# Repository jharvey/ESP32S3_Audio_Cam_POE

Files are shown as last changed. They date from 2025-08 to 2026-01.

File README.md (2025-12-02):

# ESP32S3_Audio_Cam_POE

This is a PCB layout for ESP32S3 with OV2640 / OV5640 camera. This was designeed with KiCAD version 9. 
The boards major features include:
* Camera.
* 2 way audio.
* Hardwired Ethernet including POE.
* Camera pan / tilt servos and lamp control.
* record to SD card.
* misc outputs to drive misc motors or similar outputs. 
* Battery powered option with Lion type of battery. 
* Stream video to NVR recording station. 

## Firmware
Firmware found here https://github.com/jharvey/ESP32-CAM_MJPEG2SD

Changes up to version 0.1:
* Initial layout

## Purpose

The layout design intent is to make a hardwired intercom system which includes options for camera, making a near equivilant of a doorbell camera. Hardwired means it's not susceptibale to RF jaming, or similar attacks. It can be battery powered at the ethernet switch source so it can handle power outagaged. Lighting controls allow night time spot light, and day time spot light controls. Pan, Tilt, Rotate could potentailly allow a laser pointer to distract bad players if things go bump in the night. 

## Installation
After cloning, don't forget to check out the submodule. 

TBD currently has not had it's first spin. TBD

## 3D case
See 3D case found here
TBD create file in OnShape and post link here. TBD

## 3D pictures from KICAD
<div align="center">
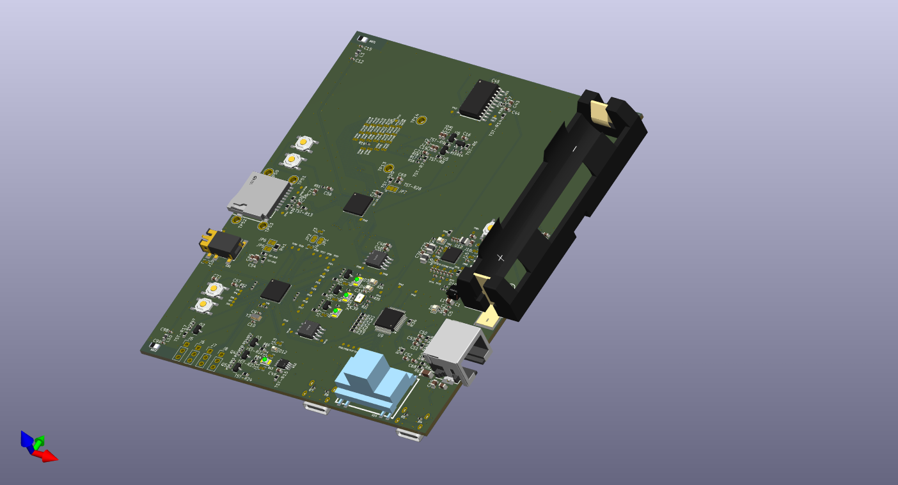
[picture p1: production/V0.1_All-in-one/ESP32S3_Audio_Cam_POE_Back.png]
ESP32S3_Cam_POE_Back

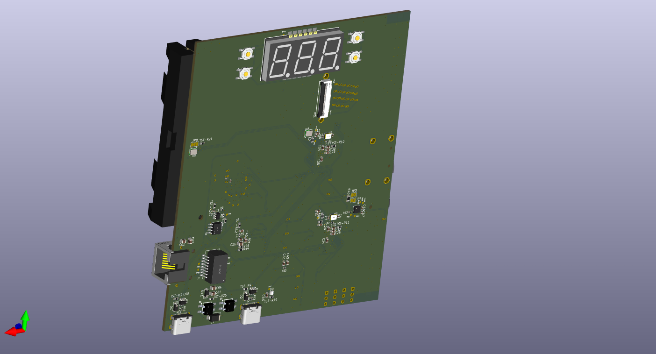
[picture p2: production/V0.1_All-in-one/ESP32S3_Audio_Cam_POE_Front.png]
ESP32S3_Cam_POE_Front

<div align="left">

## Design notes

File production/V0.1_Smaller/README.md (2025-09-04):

# ESP32S3_Audio_Cam_POE

This is a PCB layout for ESP32S3 with OV2640 / OV5640 camera. This was designeed with KiCAD version 9. 
The boards major features include:
* Camera.
* 2 way audio.
* Hardwired Ethernet including POE.
* Camera pan / tilt servos and lamp control.
* record to SD card.
* Stream video to NVR recording station. 

Changes up to version 0.1:
* Initial layout

## Installation
After cloning, don't forget to check out the submodule. 

TBD currently has not had it's first spin. TBD

## 3D case
See 3D case found here
TBD create file in OnShape and post link here. TBD

## 3D pictures from KICAD
<div align="center">
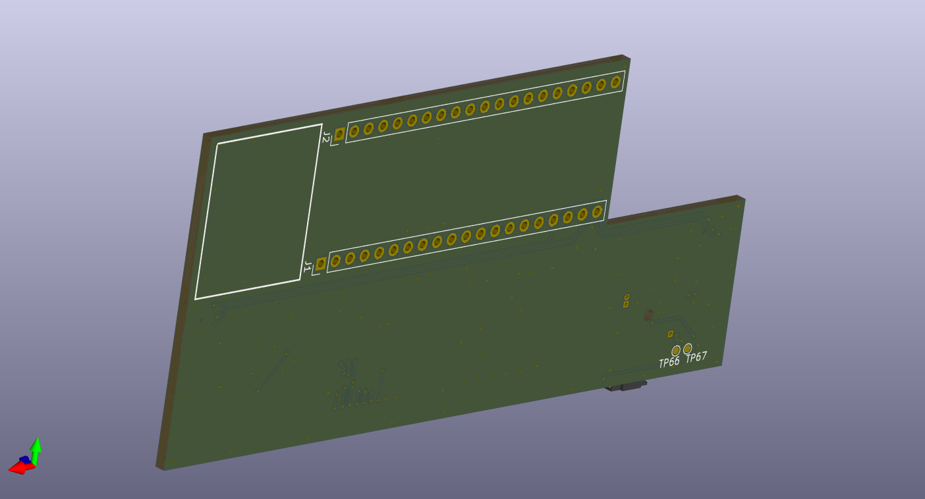
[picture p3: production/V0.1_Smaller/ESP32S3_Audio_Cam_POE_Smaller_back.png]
ESP32S3_Cam_POE_Back

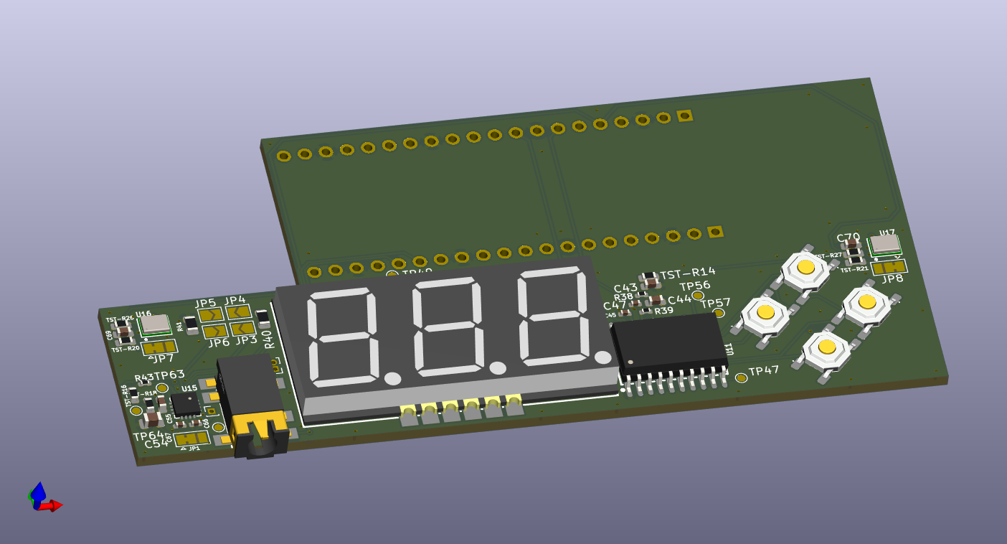
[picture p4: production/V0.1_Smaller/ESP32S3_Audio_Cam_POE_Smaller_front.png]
ESP32S3_Cam_POE_Front

<div align="left">

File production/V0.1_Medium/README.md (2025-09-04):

# ESP32S3_Audio_Cam_POE

This is a PCB layout for ESP32S3 with OV2640 / OV5640 camera. This was designeed with KiCAD version 9. 
The boards major features include:
* Camera.
* 2 way audio.
* Hardwired Ethernet including POE.
* Camera pan / tilt servos and lamp control.
* record to SD card.
* misc outputs to drive misc motors or similar outputs. 
* Battery powered option with Lion type of battery. 
* Stream video to NVR recording station. 

## Firmware
Firmware found here https://github.com/jharvey/ESP32-CAM_MJPEG2SD

Changes up to version 0.1:
* Initial layout

## Purpose

The layout design intent is to make a hardwired intercom system which includes options for camera, making a near equivilant of a doorbell camera. Hardwired means it's not susceptibale to RF jaming, or similar attacks. It can be battery powered at the ethernet switch source so it can handle power outagaged. Lighting controls allow night time spot light, and day time spot light controls. Pan, Tilt, Rotate could potentailly allow a laser pointer to distract bad players if things go bump in the night. 

## Installation
After cloning, don't forget to check out the submodule. 

TBD currently has not had it's first spin. TBD

## 3D case
See 3D case found here
TBD create file in OnShape and post link here. TBD

## 3D pictures from KICAD
<div align="center">
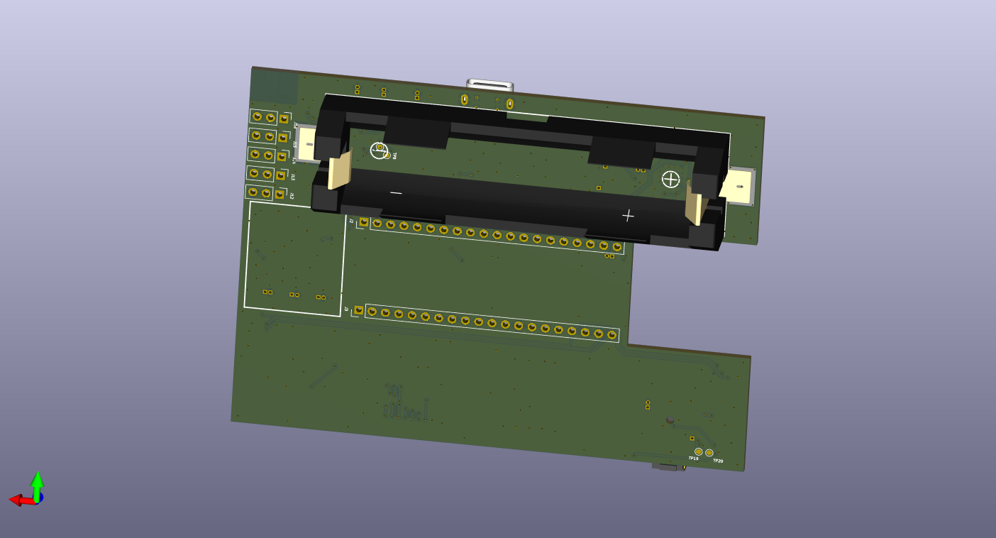
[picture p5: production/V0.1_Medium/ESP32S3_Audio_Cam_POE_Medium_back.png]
ESP32S3_Cam_POE_Back

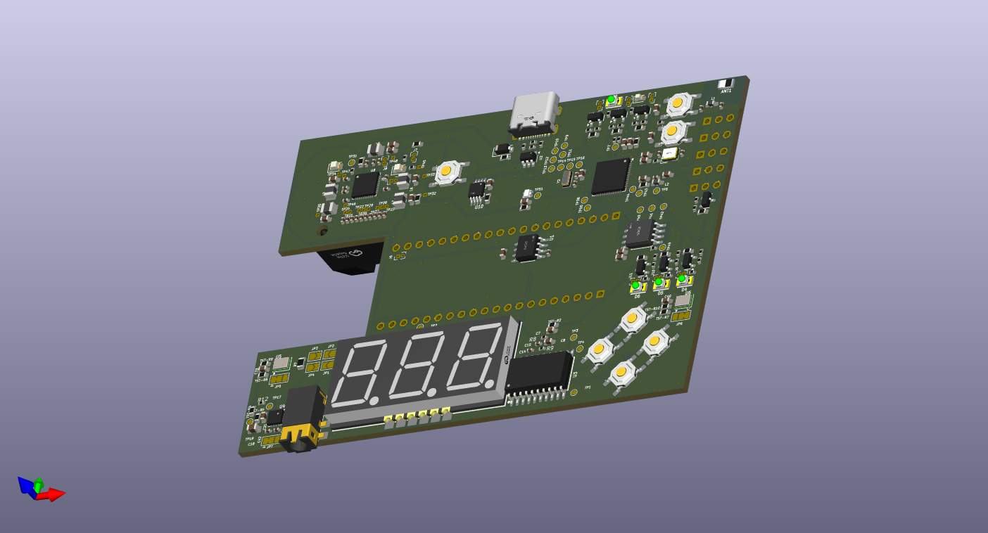
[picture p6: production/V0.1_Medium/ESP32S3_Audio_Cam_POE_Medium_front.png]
ESP32S3_Cam_POE_Front

<div align="left">

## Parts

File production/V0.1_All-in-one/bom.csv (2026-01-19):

Designator | Footprint | Quantity | Value | LCSC Part #
ANT1, ANT2 | ANT-SMD_L3.2-W1.6-KH-3216F245C04 | 2 | KH-3216-H0209 | C2925417
ANT3 | ANT-SMD_H2U646MHLQ0200 | 1 | H2U646MHLQ0200 | C5370061
BOOT1, BOOT2, PB1, PB2, PB3, PB4, PB5, RST2, RST3 | SW-SMD_4P-L5.1-W5.1-P3.70-LS6.5-TL-2 | 9 | Tactile Button, 160gf | C318884
BT1 | BATTERY-SMD_18650-1S-L77.1-W20.7-1 | 1 | BH-18650-B1BA002 | C2988620
C1 | C_0805 | 1 | 4.7uF | C1779
C10, C9 | C_0402 | 2 | 20pF | C1554
C100, C101, C11, C13, C19, C20, C21, C24, C25, C27, C28, C29, C30, C31, C32, C35, C37, C38, C41, C44, C46, C49, C5, C55, C56, C57, C58, C68, C69, C70, C71, C72 | C_0603 | 32 | 100nF | C14663
C102, C14, C74, C8 | C_0402 | 4 | 10uF | C15525
C103 | C_0805 | 1 | 10u | C15850
C104 | C_0402 | 1 | 4.7pF | C1569
C105, C12, C98 | C_0402 | 3 | 3.3pF | C1565
C106, C3, C33, C34, C4, C6, C7 | C_0402 | 7 | 10pF | C32949
C15, C99 | C_0402 | 2 | 1pF | C1550
C16, C17, C18, C23, C26, C42, C43, C48 | C_0603 | 8 | 1uF | C15849
C2 | C_0402 | 1 | 1nF | C1523
C22 | C_0402 | 1 | 15pF | C1548
C36, C54 | C_0805 | 2 | 10uF | C440198
C39 | C_0402 | 1 | 10nF | C15195
C40 | C_0603 | 1 | 4.7uF | C19666
C45, C47 | C_0402 | 2 | 100pF | C1546
C50, C51 | C_0603 | 2 | 6.8nF | C1631
C52, C53 | C_0603 | 2 | 220nF | C21120
C59, C60, C62, C63 | C_0805 | 4 | 100nF | C28233
C61 | C_0805 | 1 | 10uF | C15850
C64 | C_0805 | 1 | 22uF | C45783
C65 | C_1206 | 1 | 1nF | C9196
C66, C67 | C_0402 | 2 | 220pF | C1530
C73, C88, C90, C91, C92, C93, C94 | C_0402 | 7 | 1uF | C52923
C75, C76, C77, C78, C95, C97 | C_0603 | 6 | 22uF | C59461
C79, C80, C81, C82, C83, C84, C85, C86, C87, C96 | C_0402 | 10 | 2.2uF | C12530
C89 | C_0402 | 1 | 4.7uF | C23733
CARD1 | TF-PUSH-SD-CARD_C393941 | 1 | TF PUSH | C393941
CN1 | SMD_3.5mm_Audio_Connectors_(Headphones)_C707223 | 1 | PJ-316C-6A | C707223
D1, D11, D2 | D_SOD-123 | 3 | 1N4148W | C81598
D10 | D_0603 | 1 | Red | C2286
D12 | D_0603 | 1 | White | C2290
D13, D16, D17, D18 | IR-LED_C131280 | 4 | IR | C131280
D14, D3 | D_0805 | 2 | Yellow | C2296
D15, D4, D8 | D_0805 | 3 | Green | C2297
D5, D6 | MB6S-C82584 | 2 | MB6S | C82584
D7 | D_SMA | 1 | SMAJ58A | C19077554
D9 | LED-SMD_4P-L1.6-W1.5_XL-1615RGBC-WS2812B | 1 | WS2812B | C5349954
DISP1 | 3x7-seg_LED-RED_C2913084 | 1 | SLS0563DRA1GD | C2913084
FPC1 | OV2640_connector_AFC01-S24FCC-00 | 1 | AFC01-S24FCC-00 | C262276
J1, J2 | TYPE-C-SMD_HX-TYPE-C-16PIN | 2 | Connector, USB-TYPE-C-16P | C2927039
J10, J11, J12, J13, J14, J15, J16, J17, J18, J19, J3, J4 | PinHeader_1x02_P1.00mm_Vertical | 12 | Conn_01x02
J5, J6, J7, J8 | PinHeader_1x03_P2.54mm_Vertical | 4 | Conn_01x03
J9 | HC-RJ45-055-4_C3000211 | 1 | HC-RJ45-055-4_8P8C_Shielded | C3000211
JP1, JP2 | SolderJumper-2_P1.3mm_Bridged_RoundedPad1.0x1.5mm | 2 | Jumper_2_Small_Bridged
L1 | L_Wurth_WE-LQSH-4020 | 1 | 2.2uH | C135262
L10, L3, L4 | L_0402 | 3 | 3.9nH,300mA | C14033
L11, L2 | 0603 | 2 | 2nH | C29682
L5, L6, L7, L8, L9 | 1008 | 5 | 1uH,3.3A | C435392
NTC1 | R_0402 | 1 | NTC | C3018545
Q1, Q2, Q3, Q4, Q5, Q6, Q7, Q8 | Q_SOT-23 | 8 | AO3401A | C15127
R1, R2, R3 | R_0402 | 3 | 22Ω | C25092
R10, R11, R12, R13 | R_0402 | 4 | 33Ω | C25105
R14, R42, R54, R55, R56, R79, R8, R82 | R_0402 | 8 | 10MΩ | C26082
R15, R20, R43, R47, R57, R58, R63, R77, R80, R83 | R_0402 | 10 | 1MΩ | C26083
R16, R17, R18, R19, R28, R30, R31, R38, R39, R50, R51, R52, R53, R64, R65, R66, R67, R69, R70, R73, R75, R78, R81, R84 | R_0402 | 24 | 10kΩ | C25744
R21, R85, R86, R87 | R_0402 | 4 | 0Ω | C17168
R22, R23, R24, R25, R26, R27 | R_0603 | 6 | 20Ω | C22950
R29, R32, R36 | R_0603 | 3 | 12kΩ | C22790
R33, R37, R68, R71, R72, R9 | R_0402 | 6 | 100kΩ | C25741
R34, R35 | R_0402 | 2 | 680Ω | C25130
R4, R5, R6, R7 | R_0402 | 4 | 5.1kΩ | C25905
R40, R41 | R_0805 | 2 | 100kΩ | C149504
R44, R45, R46 | R_0603 | 3 | 47Ω | C23182
R48, R49 | R_0603 | 2 | 82Ω | C23255
R59, R60, R61, R62 | R_0603 | 4 | 75Ω | C4275
R74, R76 | R_0402 | 2 | 220kΩ | C25767
T1 | H1102NLT_C18584 | 1 | H1102NLT | C18584
TP1, TP10, TP11, TP12, TP131, TP15, TP16, TP17, TP18, TP19, TP2, TP20, TP21, TP22, TP23, TP24, TP25, TP26, TP27, TP28, TP29, TP3, TP30, TP31, TP32, TP33, TP34, TP35, TP36, TP37, TP38, TP39, TP4, TP40, TP41, TP42, TP43, TP44, TP45, TP46, TP47, TP48, TP49, TP5, TP54, TP55, TP56, TP57, TP58, TP59, TP6, TP60, TP61, TP62, TP63, TP64, TP65, TP66, TP67, TP68, TP7, TP8, TP85, TP9 | TestPoint_Pad_D1.0mm_SmallFootprint | 64 | TestPoint
TP100, TP101, TP102, TP103, TP104, TP105, TP106, TP107, TP108, TP109, TP110, TP111, TP112, TP113, TP114, TP115, TP116, TP117, TP118, TP119, TP120, TP121, TP122, TP123, TP124, TP125, TP126, TP127, TP128, TP129, TP69, TP70, TP71, TP72, TP73, TP74, TP75, TP76, TP77, TP78, TP79, TP80, TP81, TP82, TP83, TP84, TP86, TP87, TP88, TP89, TP90, TP91, TP92, TP93, TP94, TP95, TP96, TP97, TP98, TP99 | PinHeader_1x01_P1.00mm_Vertical_small-courtyard | 60 | TestPoint
TP13, TP14, TP50, TP51, TP52, TP53 | TestPoint_Plated_Hole_D2.0mm | 6 | TestPoint
TST-R1, TST-R10, TST-R11, TST-R12, TST-R13, TST-R14, TST-R15, TST-R16, TST-R17, TST-R18, TST-R19, TST-R2, TST-R20, TST-R21, TST-R22, TST-R23, TST-R24, TST-R25, TST-R26, TST-R27, TST-R28, TST-R29, TST-R3, TST-R30, TST-R31, TST-R32, TST-R33, TST-R4, TST-R5, TST-R6, TST-R7, TST-R8, TST-R9 | R_0603 | 33 | 0Ω | C21189
U1 | SOT-23-5 | 1 | TLV62568DBVR | C163219
U10, U13 | SOIC-8_L5.3-W5.3-P1.27-LS8.0-BL | 2 | W25Q128JVSIQ | C97521
U11 | digital tube drivers_c2962580 | 1 | TM1637 | C2962580
U12 | DS18B20_C695836 | 1 | DS18B20U(UMW) | C695836
U14 | DP9900M_C5380106 | 1 | DP9900M-5V | C5380106
U15 | MAX98357AETE+T_C910544 | 1 | MAX98357AETE+T
U16, U17 | ICS-43434_C5656610 | 2 | ICS-43434 | C5656610
U18 | QFN-40-1EP_5x5mm_P0.4mm_EP3.6x3.6mm_ThermalVias | 1 | AXP2101 | C3036461
U19 | RFM69HCW | 1 | RFM69HCW | C2844473
U2 | Current-sensor_MT9221CT-06BR5_C879632 | 1 | MT9221CT-06BR5 | C879632
U3, U4 | SOT-23-6 | 2 | USBLC6-2SC6 | C2827654
U5 | SOT-23-3 | 1 | XC6206-1.5NR | C2984869
U6 | SOT-23-3 | 1 | XC6206-2.8V | C41424780
U7, U8 | QFN-56-1EP_7x7mm_P0.4mm_EP4x4mm_ThermalVias | 2 | ESP32-S3 | C2913194
U9 | LQFP-48_7x7mm_P0.5mm | 1 | W5500 | C32843
X1 | OSC-SMD_4P-L3.2-W2.5-BL | 1 | X322525MOB4SI | C9006
Y1, Y2 | OSC-SMD_4P-L3.2-W2.5-BL_SIT8008BI | 2 | 40MHz, 15pF | C9010
Y3 | Crystal_SMD_3215-2Pin_3.2x1.5mm | 1 | 32.768KHz | C97604

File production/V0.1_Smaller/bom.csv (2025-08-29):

Designator | Footprint | Quantity | Value | LCSC Part #
C43 | C_0603 | 1 | 1uF | C15849
C44, C55, C69, C70 | C_0603 | 4 | 100nF | C14663
C45, C47 | C_0402 | 2 | 100pF | C1546
C54 | C_0805 | 1 | 10uF | C440198
C66, C67 | C_0402 | 2 | 220pF | C1530
CN1 | SMD_3.5mm_Audio_Connectors_(Headphones)_C707223 | 1 | PJ-316C-6A | C707223
DISP1 | 3x7-seg_LED-RED_C2913084 | 1 | SLS0563DRA1GD | C2913084
J1, J2 | PinHeader_1x20_P2.54mm_Vertical | 2 | Conn_01x20_Pin
J10 | PinHeader_1x02_P1.00mm_Vertical | 1 | Conn_01x02
PB1, PB2, PB4, PB5 | SW-SMD_4P-L5.1-W5.1-P3.70-LS6.5-TL-2 | 4 | Tactile Button, 160gf | C318884
R38, R39 | R_0402 | 2 | 10kΩ | C25744
R40, R41 | R_0805 | 2 | 100kΩ | C149504
R43 | R_0402 | 1 | 1MΩ | C26083
TP1 | PinHeader_1x01_P1.00mm_Vertical | 1 | TestPoint
TP47, TP49, TP56, TP57, TP63, TP64, TP66, TP67, TP85 | TestPoint_Pad_D1.0mm | 9 | TestPoint
TST-R14, TST-R16, TST-R18, TST-R20, TST-R21, TST-R26, TST-R27 | R_0603 | 7 | 0Ω | C21189
U11 | digital tube drivers_c2962580 | 1 | TM1637 | C2962580
U15 | MAX98357AETE+T_C910544 | 1 | MAX98357AETE+T
U16, U17 | ICS-43434_C5656610 | 2 | ICS-43434 | C5656610

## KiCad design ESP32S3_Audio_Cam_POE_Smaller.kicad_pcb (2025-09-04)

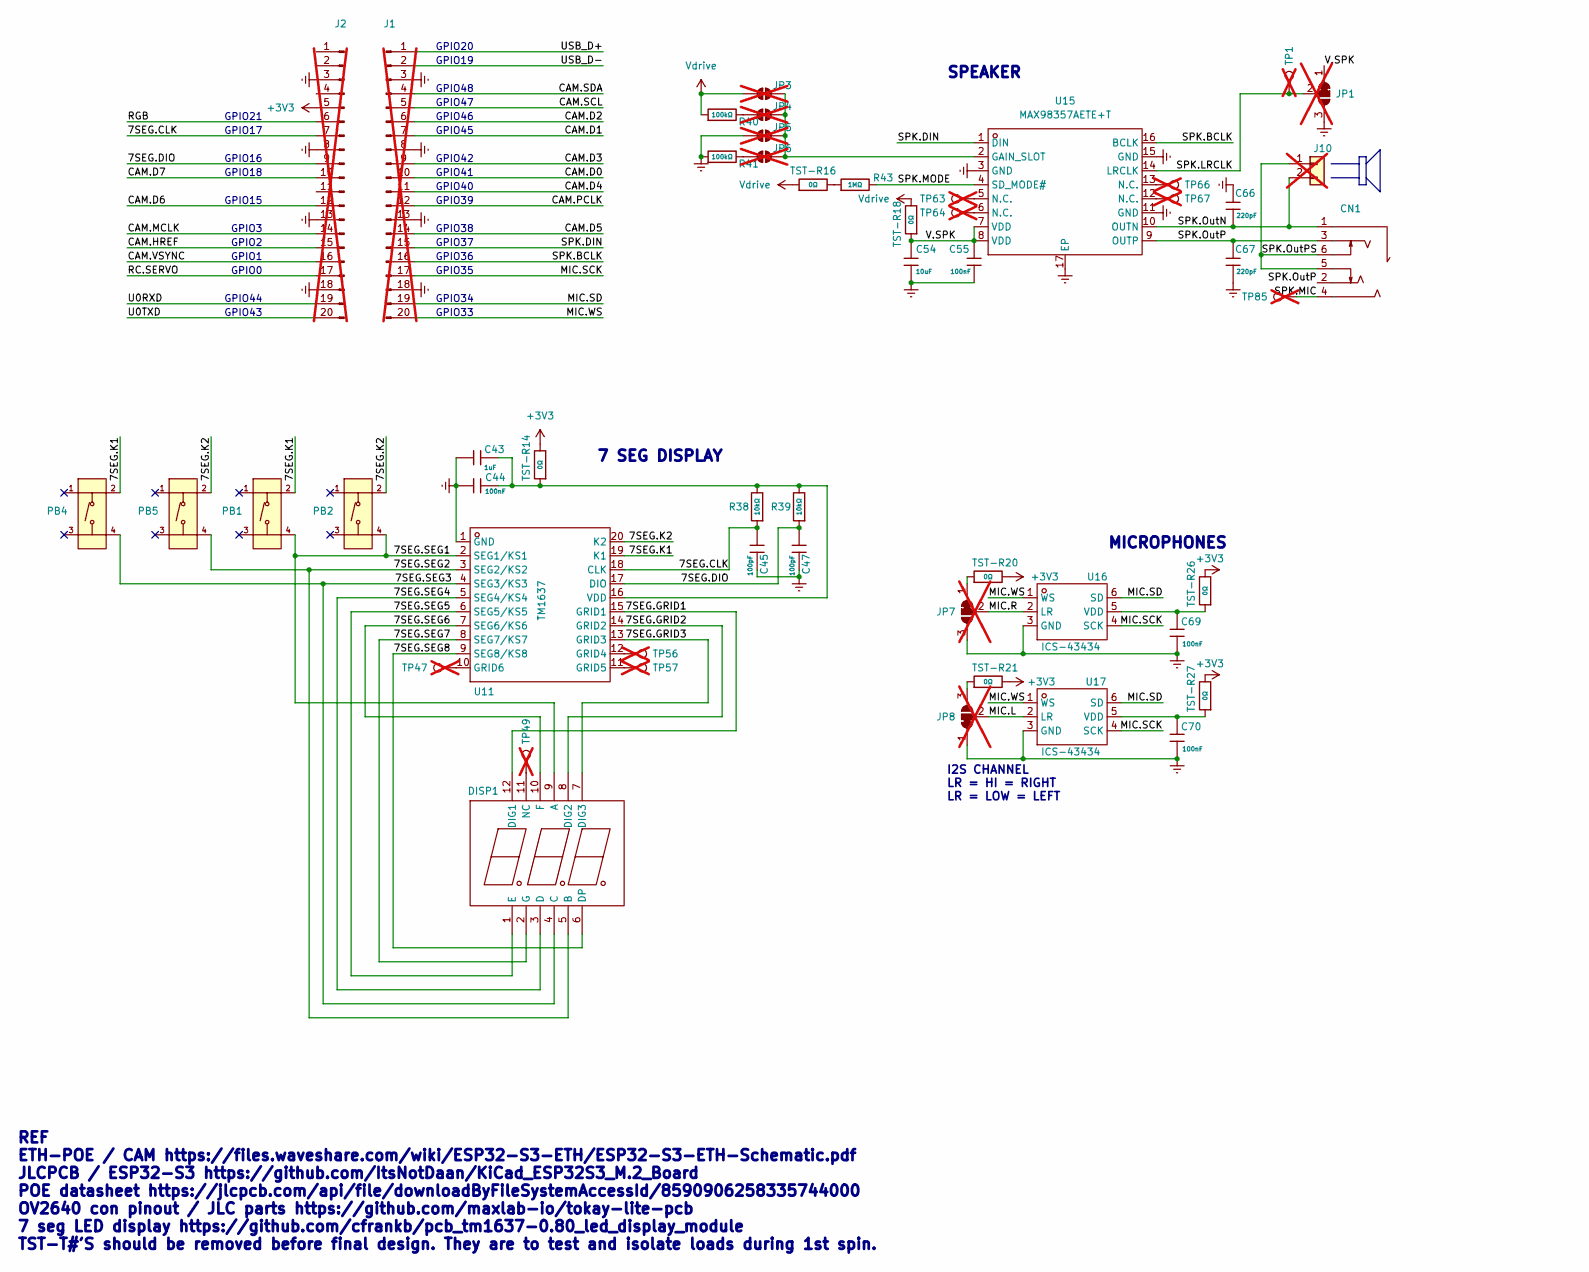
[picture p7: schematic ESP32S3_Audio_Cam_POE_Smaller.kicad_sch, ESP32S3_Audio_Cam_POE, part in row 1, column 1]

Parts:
C43: 1uF; C_0603; Voltage Rated 50V; Tolerance ±10%; Part CL10A105KB8NNNC; LCSC C15849
C44, C55, C69, C70: 100nF; C_0603; Voltage Rated 50V; Tolerance ±10%; Part CC0603KRX7R9BB104; LCSC C14663
C45, C47: 100pF; C_0402; Voltage Rated 50V; Tolerance ±5%; Part 0402CG101J500NT; LCSC C1546
C54: 10uF; C_0805; Voltage Rated 50V; Tolerance ±10%; Part GRM21BR61H106KE43L; LCSC C440198
C66, C67: 220pF; C_0402; Voltage Rated 50V; Tolerance ±10%; Part 0402B221K500NT; LCSC C1530
CN1: PJ-316C-6A; SMD_3.5mm_Audio_Connectors_(Headphones)_C707223; Manufacturer Part PJ-316C-6A; LCSC C707223
DISP1: SLS0563DRA1GD; 3x7-seg_LED-RED_C2913084; LCSC C2913084
J1, J2: Conn_01x20_Pin; PinHeader_1x20_P2.54mm_Vertical; not fitted
J10: Conn_01x02; PinHeader_1x02_P1.00mm_Vertical; not fitted
JP1, JP7, JP8: SolderJumper_3_Bridged12; SolderJumper-3_P1.3mm_Bridged12_Pad1.0x1.5mm; not fitted
JP3, JP4, JP5, JP6: SolderJumper_2_Open; SolderJumper-2_P1.3mm_Open_TrianglePad1.0x1.5mm; not fitted
PB1, PB2, PB4, PB5: Tactile Button, 160gf; SW-SMD_4P-L5.1-W5.1-P3.70-LS6.5-TL-2; Voltage Rating (Dc) 12V; Part TS-1187A-B-A-B; LCSC C318884
R38, R39: 10kΩ; R_0402; Overload Voltage (Max) 50V; Tolerance ±1%; Part 0402WGF1002TCE; LCSC C25744
R40, R41: 100kΩ; R_0805; Overload Voltage (Max) 150V; Tolerance ±1%; Part 0805W8F1003T5E; LCSC C149504
R43: 1MΩ; R_0402; Overload Voltage (Max) 50V; Tolerance ±1%; Part 0402WGF1004TCE; LCSC C26083
TP1: TestPoint; PinHeader_1x01_P1.00mm_Vertical; not fitted
TP47, TP49, TP56, TP57, TP63, TP64, TP66, TP67, TP85: TestPoint; TestPoint_Pad_D1.0mm; not fitted
TST-R14, TST-R16, TST-R18, TST-R20, TST-R21, TST-R26, TST-R27: 0Ω; R_0603; Overload Voltage (Max) 75V; Tolerance ±1%; Part 0603WAF0000T5E; LCSC C21189
U11: TM1637; digital tube drivers_c2962580; LCSC C2962580
U15: MAX98357AETE+T; MAX98357AETE+T_C910544; Manufacturer Part MAX98357AETE+T
U16, U17: ICS-43434; ICS-43434_C5656610; LCSC C5656610

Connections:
+3V3: J2.5, TST-R14.2, TST-R20.2, TST-R21.2, TST-R26.2, TST-R27.2
/7SEG.CLK: C45.2, J2.7, R38.1, U11.18 (CLK)
/7SEG.DIO: C47.2, J2.9, R39.1, U11.17 (DIO)
/7SEG.GRID1: DISP1.12 (DIG1), U11.15 (GRID1)
/7SEG.GRID2: DISP1.8 (DIG2), U11.14 (GRID2)
/7SEG.GRID3: DISP1.7 (DIG3), U11.13 (GRID3)
/7SEG.K1: PB1.2 (B), PB4.2 (B), U11.19 (K1)
/7SEG.K2: PB2.2 (B), PB5.2 (B), U11.20 (K2)
/7SEG.SEG1: DISP1.9 (A), PB1.4 (D), PB2.4 (D), U11.2 (SEG1/KS1)
/7SEG.SEG2: DISP1.5 (B), PB5.4 (D), U11.3 (SEG2/KS2)
/7SEG.SEG3: DISP1.4 (C), PB4.4 (D), U11.4 (SEG3/KS3)
/7SEG.SEG4: DISP1.3 (D), U11.5 (SEG4/KS4)
/7SEG.SEG5: DISP1.1 (E), U11.6 (SEG5/KS5)
/7SEG.SEG6: DISP1.10 (F), U11.7 (SEG6/KS6)
/7SEG.SEG7: DISP1.2 (G), U11.8 (SEG7/KS7)
/7SEG.SEG8: DISP1.6 (DP), U11.9 (SEG8/KS8)
/CAM.D0: J1.10
/CAM.D1: J1.7
/CAM.D2: J1.6
/CAM.D3: J1.9
/CAM.D4: J1.11
/CAM.D5: J1.14
/CAM.D6: J2.12
/CAM.D7: J2.10
/CAM.HREF: J2.15
/CAM.MCLK: J2.14
/CAM.PCLK: J1.12
/CAM.SCL: J1.5
/CAM.SDA: J1.4
/CAM.VSYNC: J2.16
/MIC.L: JP8.2 (C), U17.2 (LR)
/MIC.R: JP7.2 (C), U16.2 (LR)
/MIC.SCK: J1.17, U16.4 (SCK), U17.4 (SCK)
/MIC.SD: J1.19, U16.6 (SD), U17.6 (SD)
/MIC.WS: J1.20, U16.1 (WS), U17.1 (WS)
/RC.SERVO: J2.17
/RGB: J2.6
/SPK.BCLK: J1.16, U15.16 (BCLK)
/SPK.DIN: J1.15, U15.1 (DIN)
/SPK.LRCLK: JP1.2 (C), TP1.1, U15.14 (LRCLK)
/SPK.MIC: CN1.4, TP85.1
/SPK.MODE: R43.2, U15.4 (SD_MODE#)
/SPK.OutN: C66.2, CN1.1, J10.2, U15.10 (OUTN)
/SPK.OutP: C67.1, CN1.2, CN1.3, U15.9 (OUTP)
/SPK.OutPS: CN1.5, CN1.6, J10.1
/U0RXD: J2.19
/U0TXD: J2.20
/USB_D+: J1.1
/USB_D-: J1.2
/V.SPK: C54.1, C55.1, JP1.1 (A), TST-R18.1, U15.7 (VDD), U15.8 (VDD)
COM: C43.1, C44.2, C45.1, C47.1, C54.2, C55.2, C66.1, C67.2, C69.1, C70.1, J1.3, J1.8, J1.13, J1.18, J2.3, J2.8, J2.13, J2.18, JP1.3 (B), JP5.1 (A), JP7.3 (B), JP8.1 (A), R41.1, U11.1 (GND), U15.3 (GND), U15.11 (GND), U15.15 (GND), U15.17 (EP), U16.3 (GND), U17.3 (GND)
unnamed: DISP1.11 (NC), TP49.1
unnamed: JP3.2 (B), JP4.2 (B), JP5.2 (B), JP6.2 (B), U15.2 (GAIN_SLOT)
unnamed: JP4.1 (A), R40.2
unnamed: JP6.1 (A), R41.2
unnamed: JP7.1 (A), TST-R20.1
unnamed: JP8.3 (B), TST-R21.1
unnamed: R43.1, TST-R16.2
unnamed: TP63.1, U15.5 (N.C.)
unnamed: TP64.1, U15.6 (N.C.)
unnamed: TP66.1, U15.13 (N.C.)
unnamed: TP67.1, U15.12 (N.C.)
unnamed: TP56.1, U11.12 (GRID4)
unnamed: TP57.1, U11.11 (GRID5)
unnamed: TP47.1, U11.10 (GRID6)
unnamed: C43.2, C44.1, R38.2, R39.2, TST-R14.1, U11.16 (VDD)
unnamed: C69.2, TST-R26.1, U16.5 (VDD)
unnamed: C70.2, TST-R27.1, U17.5 (VDD)
Vdrive: JP3.1 (A), R40.1, TST-R16.1, TST-R18.2

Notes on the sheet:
GPIO15
GPIO37
GPIO0
expected risky area -- camera connector pinout, is pin1 really pin 1 not 24? -- I2S microphones and amplifier, should they be the same lines like code suggests -- I2C, does this need pull up, or can internal pullup suffice? -- POE ethernet, complete unknown. Fingers crossed. TODO -- make office con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
GPIO21
MICROPHONES
GPIO46
GPIO36
GPIO34
I2S CHANNEL LR = HI = RIGHT LR = LOW = LEFT
GPIO1
GPIO20
GPIO3
GPIO18
GPIO48
GPIO41
GPIO33
GPIO19
GPIO44
REF ETH-POE / CAM https://files.waveshare.com/wiki/ESP32-S3-ETH/ESP32-S3-ETH-Schematic.pdf JLCPCB / ESP32-S3 https://github.com/ItsNotDaan/KiCad_ESP32S3_M.2_Board POE datasheet https://jlcpcb.com/api/file/downloadByFileSystemAccessId/8590906258335744000 OV2640 con pinout / JLC parts https://github.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
SPEAKER
GPIO47
GPIO35
GPIO43
GPIO42
GPIO40
7 SEG DISPLAY
GPIO2
GPIO45
GPIO38
GPIO39
GPIO17
GPIO16

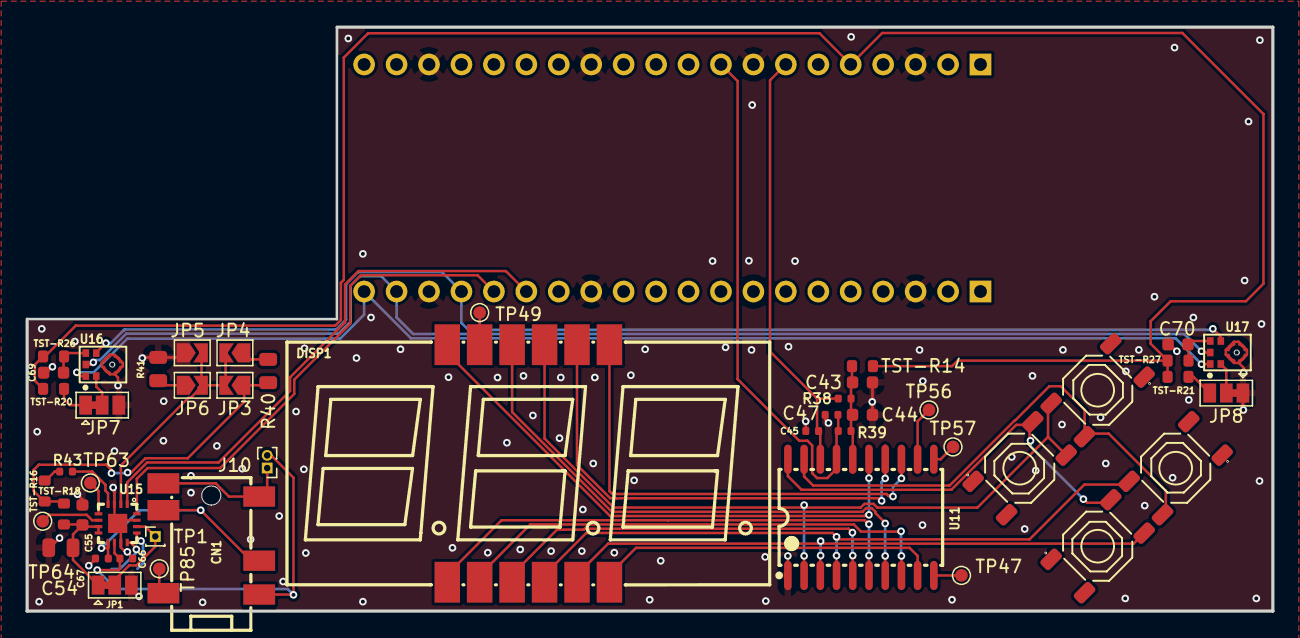
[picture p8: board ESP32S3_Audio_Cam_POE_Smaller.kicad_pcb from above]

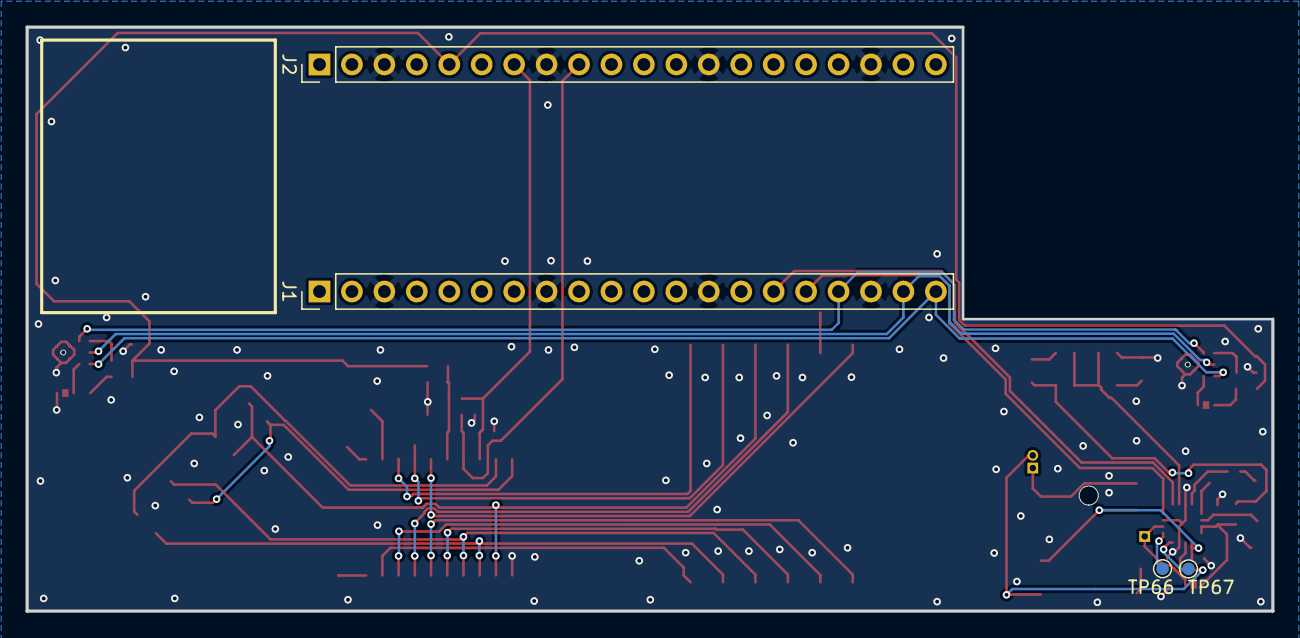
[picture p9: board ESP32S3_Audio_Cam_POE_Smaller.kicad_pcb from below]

Board: 2 copper layers, 97.5 x 45.7 mm, 52 parts (4 on the bottom side), 49 nets.

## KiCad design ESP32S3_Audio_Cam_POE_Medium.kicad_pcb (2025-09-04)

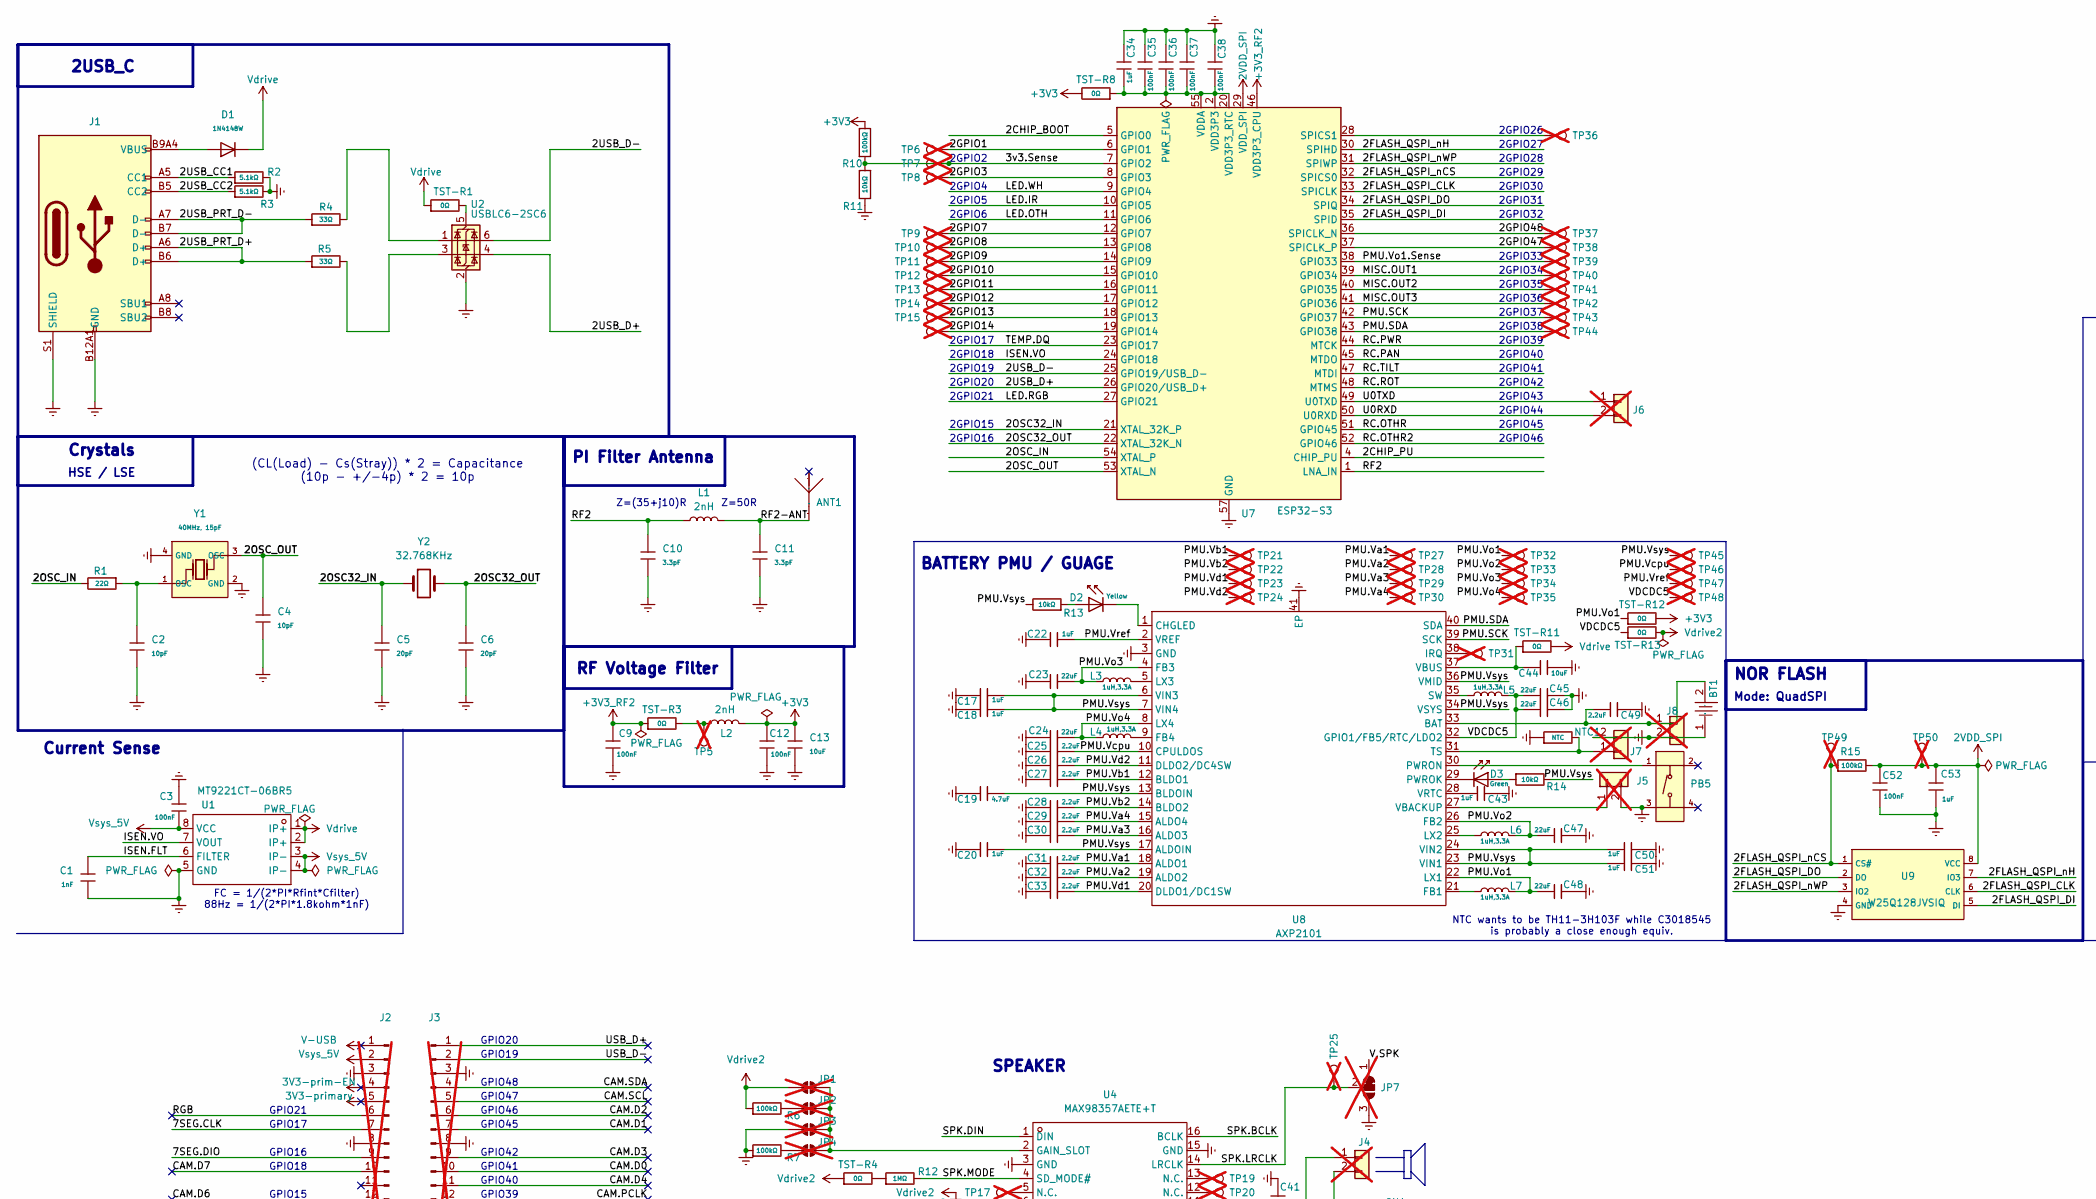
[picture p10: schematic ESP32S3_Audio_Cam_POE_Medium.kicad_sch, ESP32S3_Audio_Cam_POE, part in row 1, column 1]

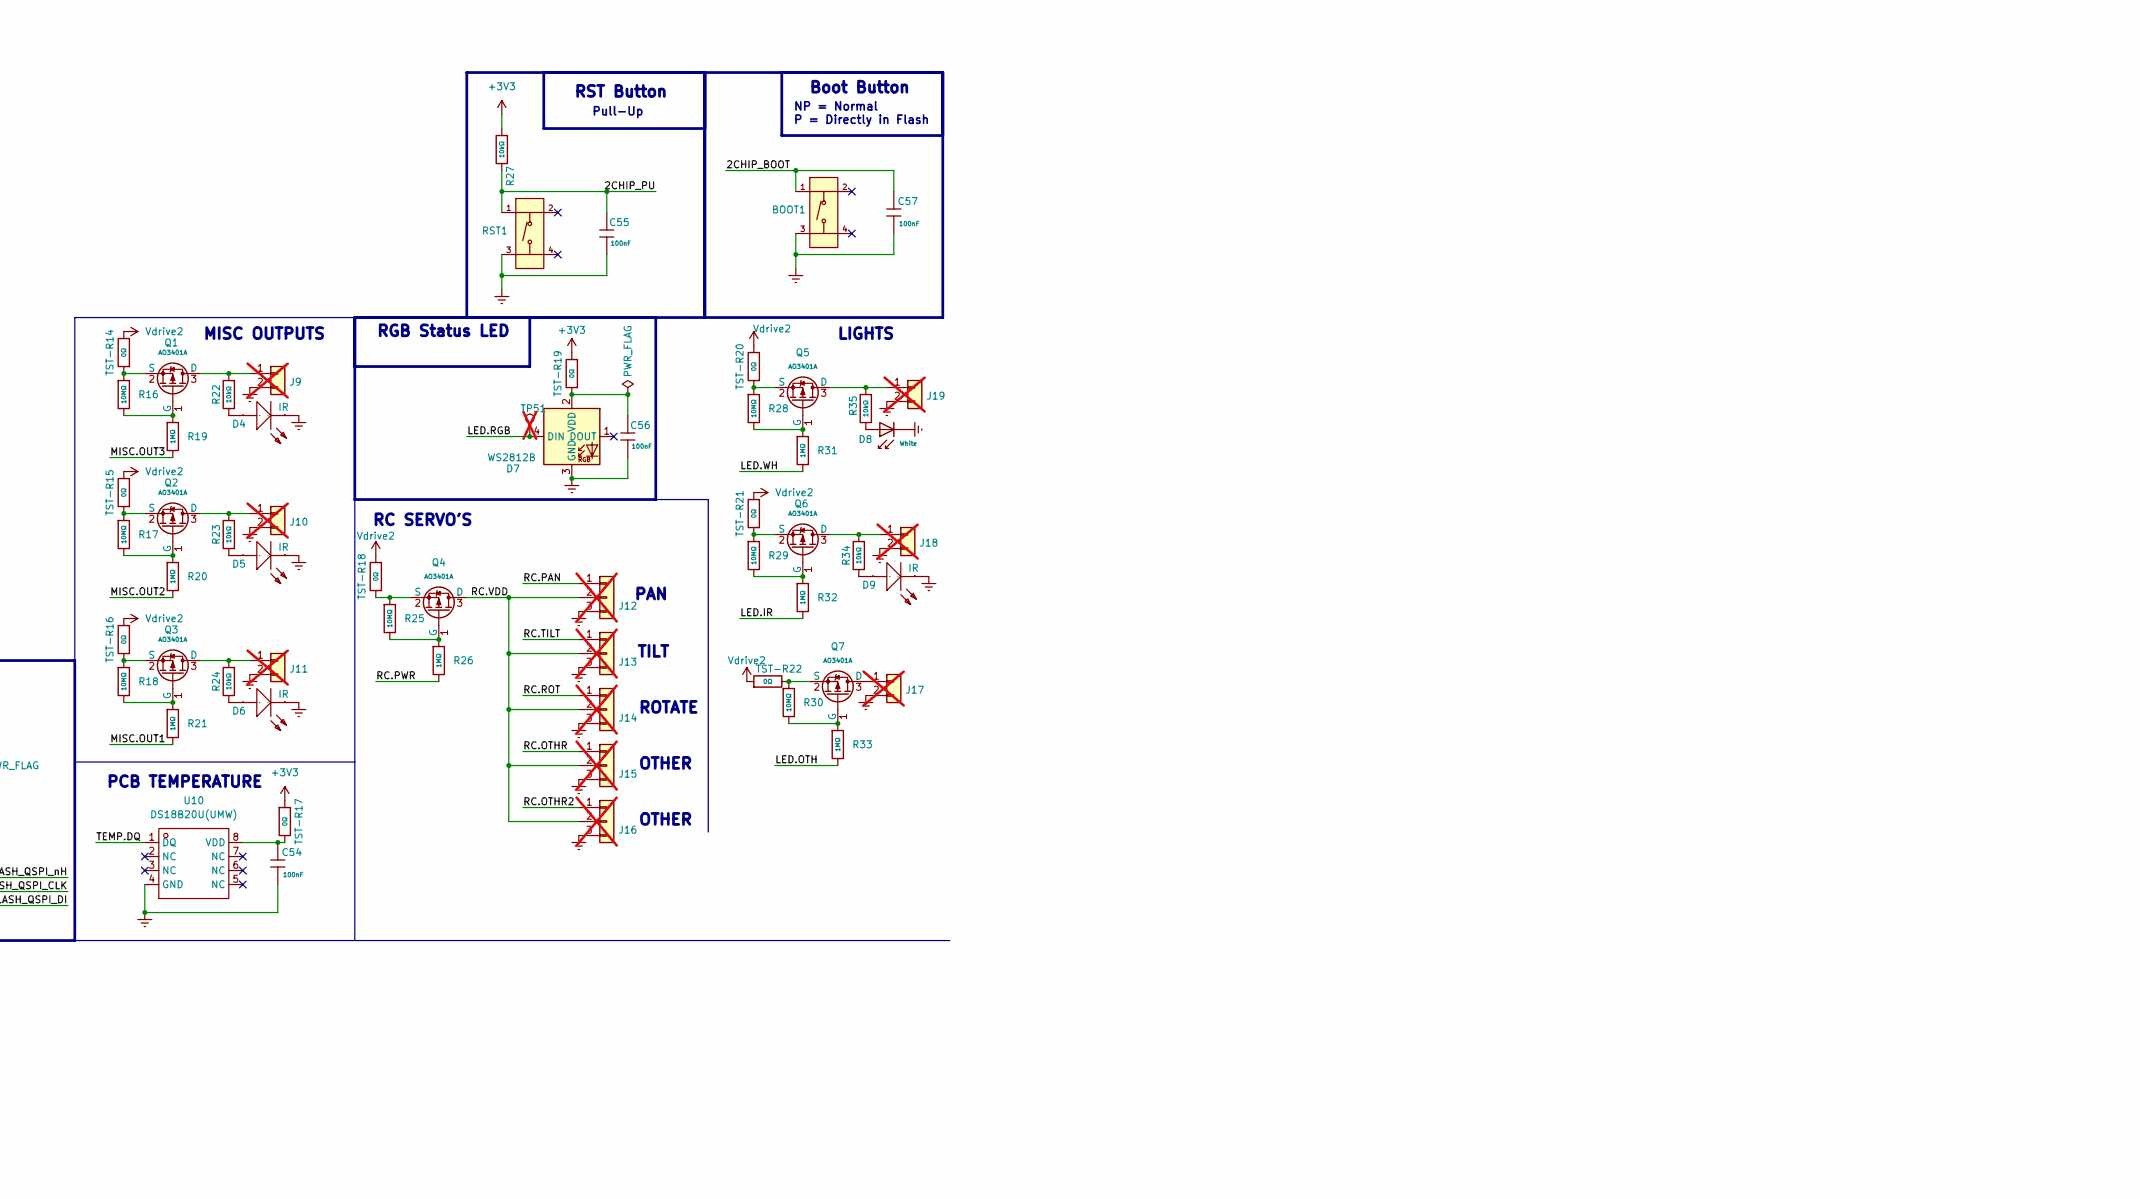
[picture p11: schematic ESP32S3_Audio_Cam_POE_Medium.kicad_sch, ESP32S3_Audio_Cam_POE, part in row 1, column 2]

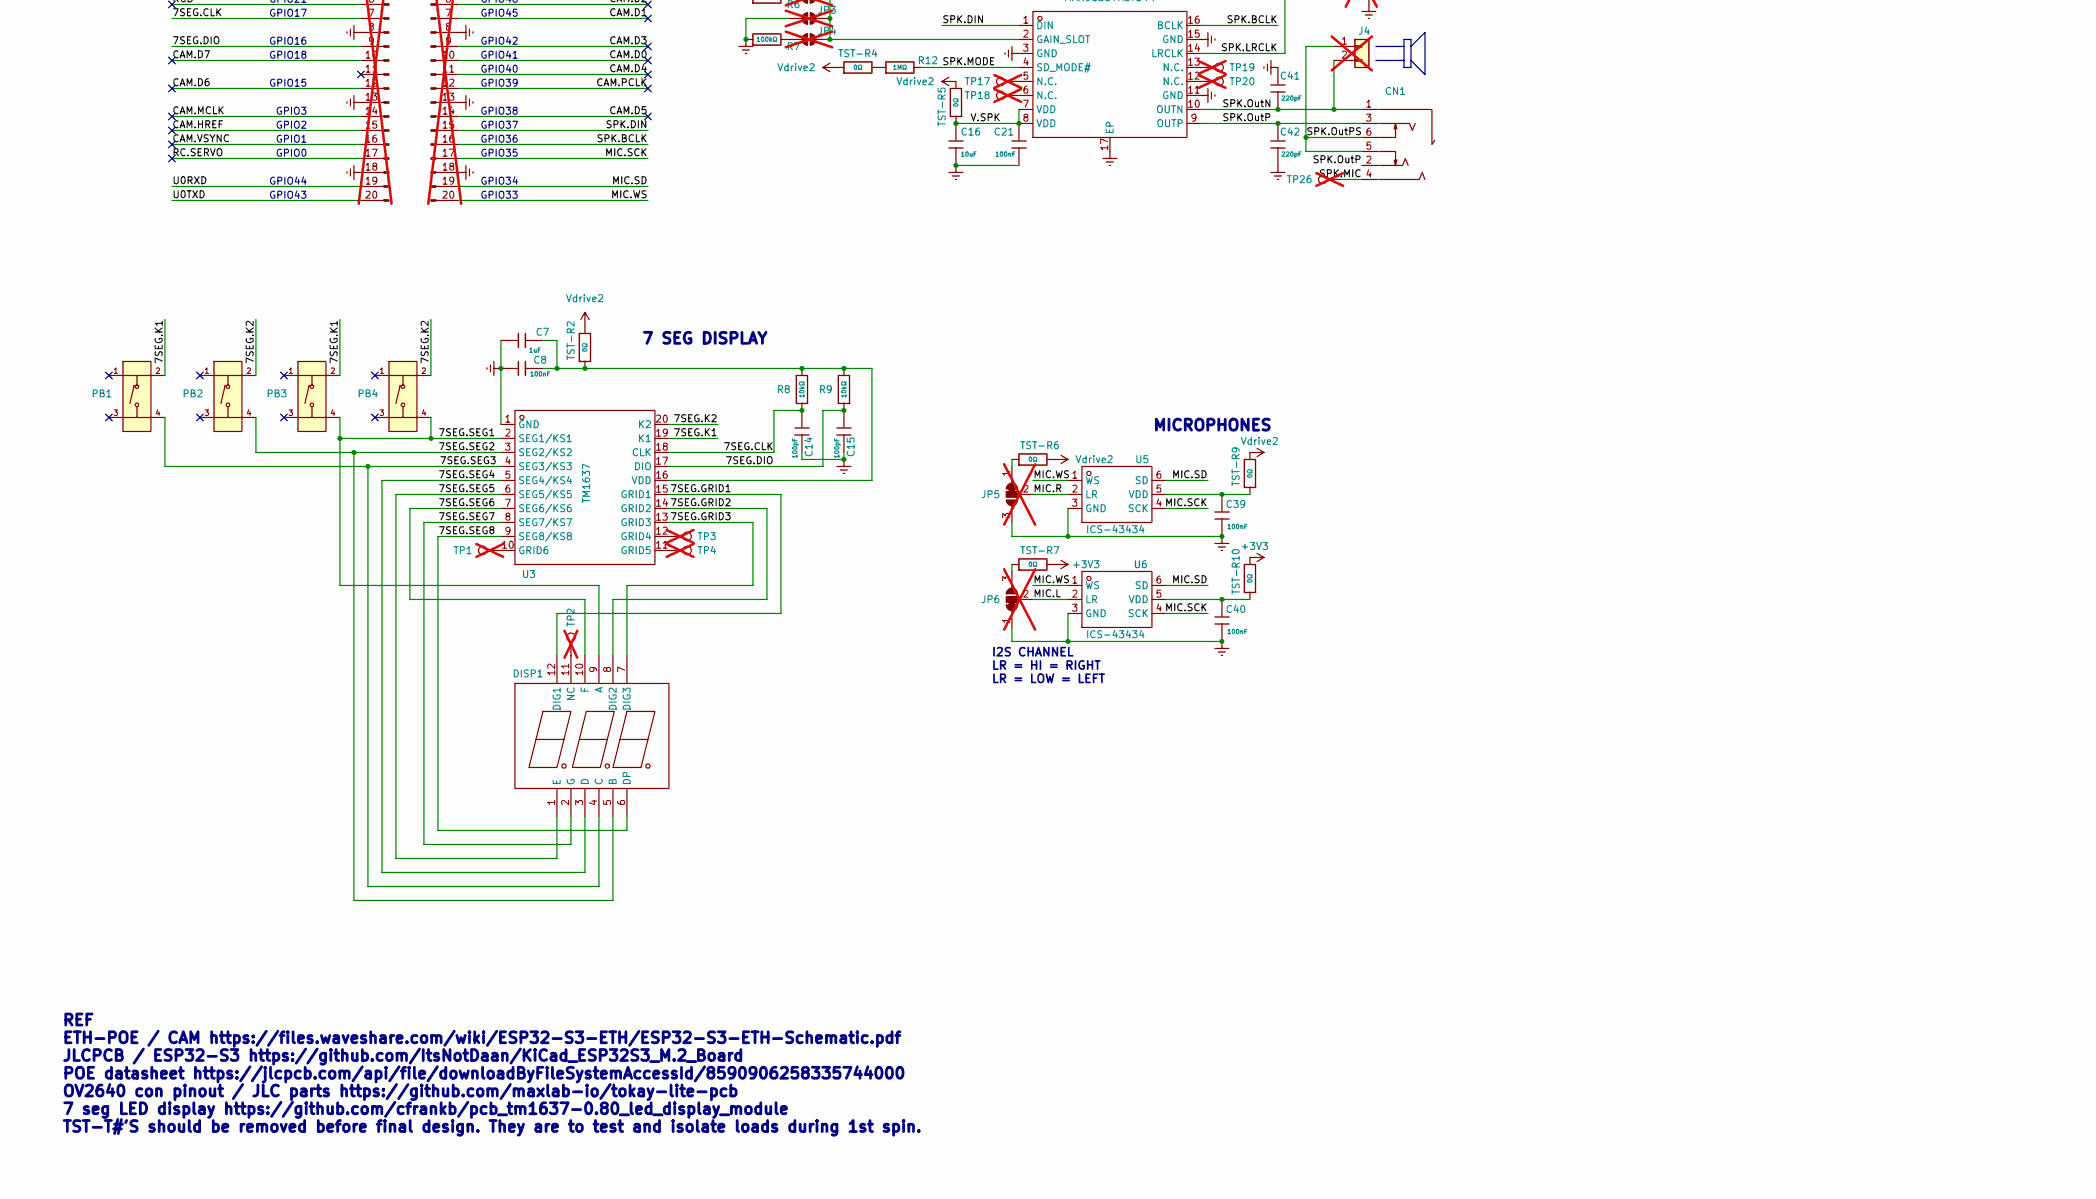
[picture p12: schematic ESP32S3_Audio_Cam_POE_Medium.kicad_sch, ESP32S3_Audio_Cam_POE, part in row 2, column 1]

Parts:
ANT1: KH-3216-H0209; ANT-SMD_L3.2-W1.6-KH-3216F245C04; Manufacturer_Part_Number KH-3216-H0209; LCSC PART # C2925417
BOOT1: Tactile Button, 160gf; SW-SMD_4P-L5.1-W5.1-P3.70-LS6.5-TL-2; Voltage Rating (Dc) 12V; Part TS-1187A-B-A-B; LCSC C318884
BT1: BH-18650-B1BA002; BATTERY-SMD_18650-1S-L77.1-W20.7-1; Manufacturer Part BH-18650-B1BA002; LCSC C2988620
C1: 1nF; C_0402; Voltage Rated 50V; Tolerance ±10%; Part 0402B102K500NT; LCSC C1523
C2, C4: 10pF; C_0402; Voltage Rated 50V; Tolerance ±5%; Part CL05C100JB5NNNC; LCSC C32949
C3, C8, C9, C12, C21, C35, C36, C37, C38, C39, C40, C52, C54, C55, C56, C57: 100nF; C_0603; Voltage Rated 50V; Tolerance ±10%; Part CC0603KRX7R9BB104; LCSC C14663
C5, C6: 20pF; C_0402; Voltage Rated 50V; Tolerance ±5%; Part 0402CG200J500NT; LCSC C1554
C7, C34, C53: 1uF; C_0603; Voltage Rated 50V; Tolerance ±10%; Part CL10A105KB8NNNC; LCSC C15849
C10, C11: 3.3pF; C_0402; Voltage Rated 50V; Part 0402CG3R3C500NT; LCSC C1565
C13, C44: 10uF; C_0402; Voltage Rated 6.3V; Tolerance ±20%; Part CL05A106MQ5NUNC; LCSC C15525
C14, C15: 100pF; C_0402; Voltage Rated 50V; Tolerance ±5%; Part 0402CG101J500NT; LCSC C1546
C16: 10uF; C_0805; Voltage Rated 50V; Tolerance ±10%; Part GRM21BR61H106KE43L; LCSC C440198
C17, C18, C20, C22, C43, C50, C51: 1uF; C_0402; Voltage Rated 25V; Tolerance ±10%; Part CL05A105KA5NQNC; LCSC C52923
C19: 4.7uF; C_0402; Voltage Rated 10V; Tolerance ±20%; Part CL05A475MP5NRNC; LCSC C23733
C23, C24, C45, C46, C47, C48: 22uF; C_0603; Voltage Rated 6.3V; Tolerance ±20%; Part CL10A226MQ8NRNC; LCSC C59461
C25, C26, C27, C28, C29, C30, C31, C32, C33, C49: 2.2uF; C_0402; Voltage Rated 6.3V; Tolerance ±20%; Part CL05A225MQ5NSNC; LCSC C12530
C41, C42: 220pF; C_0402; Voltage Rated 50V; Tolerance ±10%; Part 0402B221K500NT; LCSC C1530
CN1: PJ-316C-6A; SMD_3.5mm_Audio_Connectors_(Headphones)_C707223; Manufacturer Part PJ-316C-6A; LCSC C707223
D1: 1N4148W; D_SOD-123; Forward Voltage (Vf@If) 1V@50mA; Reverse Voltage (Vr) 75V; Part 1N4148W; LCSC C81598
D2: Yellow; D_0805; Part KT-0805Y; LCSC C2296
D3: Green; D_0805; Part KT-0805G; LCSC C2297
D4, D5, D6, D9: IR; IR-LED_C131280; LCSC C131280
D7: WS2812B; LED-SMD_4P-L1.6-W1.5_XL-1615RGBC-WS2812B; LCSC C5349954
D8: White; D_0603; Part KT-0603W; LCSC C2290
DISP1: SLS0563DRA1GD; 3x7-seg_LED-RED_C2913084; LCSC C2913084
J1: Connector, USB-TYPE-C-16P; TYPE-C-SMD_HX-TYPE-C-16PIN; LCSC C2927039
J2, J3: Conn_01x20_Pin; PinHeader_1x20_P2.54mm_Vertical; not fitted
J4, J5, J6, J7, J8, J9, J10, J11, J17, J18, J19: Conn_01x02; PinHeader_1x02_P1.00mm_Vertical; not fitted
J12, J13, J14, J15, J16: Conn_01x03; PinHeader_1x03_P2.54mm_Vertical; not fitted
JP1, JP2, JP3, JP4: SolderJumper_2_Open; SolderJumper-2_P1.3mm_Open_TrianglePad1.0x1.5mm; not fitted
JP5, JP6, JP7: SolderJumper_3_Bridged12; SolderJumper-3_P1.3mm_Bridged12_Pad1.0x1.5mm; not fitted
L1, L2: 2nH; L_0603_1608Metric_Pad1.05x0.95mm_HandSolder; LCSC PART # C29682
L3, L4, L5, L6, L7: 1uH,3.3A; L_1008_2520Metric; Tolerance ±10%; Part SDFL2012Q1R0KTF; LCSC C435392
NTC1: NTC; R_0402; Overload Voltage (Max) 50V; Tolerance ±1%; Part 0402WGF1002TCE; LCSC C3018545
PB1, PB2, PB3, PB4, PB5: Tactile Button, 160gf; SW-SMD_4P-L5.1-W5.1-P3.70-LS6.5-TL-2; Voltage Rating (Dc) 12V; Part TS-1187A-B-A-B; LCSC C318884
Q1, Q2, Q3, Q4, Q5, Q6, Q7: AO3401A; Q_SOT-23; Part AO3401A; LCSC C15127
R1: 22Ω; R_0402; Overload Voltage (Max) 50V; Tolerance ±1%; Part 0402WGF220JTCE; LCSC C25092
R2, R3: 5.1kΩ; R_0402; Overload Voltage (Max) 50V; Tolerance ±1%; Part 0402WGF5101TCE; LCSC C25905
R4, R5: 33Ω; R_0402; Overload Voltage (Max) 50V; Tolerance ±1%; Part 0402WGF330JTCE; LCSC C25105
R6, R7: 100kΩ; R_0805; Overload Voltage (Max) 150V; Tolerance ±1%; Part 0805W8F1003T5E; LCSC C149504
R8, R9, R11, R13, R14, R22, R23, R24, R27, R34, R35: 10kΩ; R_0402; Overload Voltage (Max) 50V; Tolerance ±1%; Part 0402WGF1002TCE; LCSC C25744
R10, R15: 100kΩ; R_0402; Overload Voltage (Max) 50V; Tolerance ±1%; Part 0402WGF1003TCE; LCSC C25741
R12, R19, R20, R21, R26, R31, R32, R33: 1MΩ; R_0402; Overload Voltage (Max) 50V; Tolerance ±1%; Part 0402WGF1004TCE; LCSC C26083
R16, R17, R18, R25, R28, R29, R30: 10MΩ; R_0402; Overload Voltage (Max) 50V; Tolerance ±1%; Part 0402WGF1005TCE; LCSC C26082
RST1: Tactile Button, 160gf; SW-SMD_4P-L5.1-W5.1-P3.70-LS6.5-TL-2; Voltage Rating (Dc) 12V; Part TS-1187A-B-A-B; LCSC C318884
TP1, TP2, TP3, TP4, TP5, TP6, TP7, TP8, TP9, TP10, TP11, TP12, TP13, TP14, TP15, TP16, TP17, TP18, TP19, TP20, TP26, TP31, TP36, TP37, TP38, TP39, TP40, TP41, TP42, TP43, TP44, TP49, TP50, TP51: TestPoint; TestPoint_Pad_D1.0mm; not fitted
TP21, TP22, TP23, TP24, TP25, TP27, TP28, TP29, TP30, TP32, TP33, TP34, TP35, TP45, TP46, TP47, TP48: TestPoint; PinHeader_1x01_P1.00mm_Vertical; not fitted
TST-R1, TST-R2, TST-R3, TST-R4, TST-R5, TST-R6, TST-R7, TST-R8, TST-R9, TST-R10, TST-R11, TST-R12, TST-R13, TST-R14, TST-R15, TST-R16, TST-R17, TST-R18, TST-R19, TST-R20, TST-R21, TST-R22: 0Ω; R_0603; Overload Voltage (Max) 75V; Tolerance ±1%; Part 0603WAF0000T5E; LCSC C21189
U1: MT9221CT-06BR5; Current-sensor_MT9221CT-06BR5_C879632; LCSC C879632
U2: USBLC6-2SC6; SOT-23-6; Manufacturer_Part_Number USBLC6-2SC6; LCSC PART # C2827654
U3: TM1637; digital tube drivers_c2962580; LCSC C2962580
U4: MAX98357AETE+T; MAX98357AETE+T_C910544; Manufacturer Part MAX98357AETE+T
U5, U6: ICS-43434; ICS-43434_C5656610; LCSC C5656610
U7: ESP32-S3; QFN-56-1EP_7x7mm_P0.4mm_EP4x4mm_ThermalVias; LCSC C2913194
U8: AXP2101; QFN-40-1EP_5x5mm_P0.4mm_EP3.6x3.6mm_ThermalVias; LCSC C3036461
U9: W25Q128JVSIQ; SOIC-8_L5.3-W5.3-P1.27-LS8.0-BL; Part W25Q128JVSIQ; LCSC PART # C97521
U10: DS18B20U(UMW); DS18B20_C695836; LCSC C695836
Y1: 40MHz, 15pF; OSC-SMD_4P-L3.2-W2.5-BL_SIT8008BI; PartID X322540MPB4SI; LCSC C9010
Y2: 32.768KHz; Crystal_SMD_3215-2Pin_3.2x1.5mm; Manufacturer_Part_Number DST310S 32.768KHz; LCSC PART # C97604

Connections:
2VDD_SPI: C52.2, C53.1, R15.2, TP50.1, U7.29 (VDD_SPI), U9.8 (VCC)
3V3-prim-EN: J2.4
3V3-primary: J2.5
+3V3: C12.2, C13.1, L2.2, R10.2, R27.2, TST-R7.2, TST-R8.2, TST-R10.2, TST-R12.2, TST-R17.1, TST-R19.2
+3V3_RF2: C9.2, TST-R3.1, U7.46 (VDD3P3_CPU)
/2CHIP_BOOT: BOOT1.1 (A), C57.2, U7.5 (GPIO0)
/2CHIP_PU: C55.2, R27.1, RST1.1 (A), U7.4 (CHIP_PU)
/2FLASH_QSPI_CLK: U7.33 (SPICLK), U9.6 (CLK)
/2FLASH_QSPI_DI: U7.35 (SPID), U9.5 (DI)
/2FLASH_QSPI_DO: U7.34 (SPIQ), U9.2 (DO)
/2FLASH_QSPI_nCS: R15.1, TP49.1, U7.32 (SPICS0), U9.1 (CS#)
/2FLASH_QSPI_nH: U7.30 (SPIHD), U9.7 (IO3)
/2FLASH_QSPI_nWP: U7.31 (SPIWP), U9.3 (IO2)
/2GPIO1: TP6.1, U7.6 (GPIO1)
/2GPIO3: TP8.1, U7.8 (GPIO3)
/2GPIO7: TP9.1, U7.12 (GPIO7)
/2GPIO8: TP10.1, U7.13 (GPIO8)
/2GPIO9: TP11.1, U7.14 (GPIO9)
/2GPIO10: TP12.1, U7.15 (GPIO10)
/2GPIO11: TP13.1, U7.16 (GPIO11)
/2GPIO12: TP14.1, U7.17 (GPIO12)
/2GPIO13: TP15.1, U7.18 (GPIO13)
/2GPIO14: TP16.1, U7.19 (GPIO14)
/2GPIO47: TP38.1, U7.37 (SPICLK_P)
/2GPIO48: TP37.1, U7.36 (SPICLK_N)
/2OSC32_IN: C5.1, U7.21 (XTAL_32K_P), Y2.1
/2OSC32_OUT: C6.1, U7.22 (XTAL_32K_N), Y2.2
/2OSC_IN: R1.2, U7.54 (XTAL_P)
/2OSC_OUT: C4.1, U7.53 (XTAL_N), Y1.3 (OSC)
/2USB_CC1: J1.A5 (CC1), R2.1
/2USB_CC2: J1.B5 (CC2), R3.1
/2USB_D+: U2.4 (I/O2), U7.26 (GPIO20/USB_D+)
/2USB_D-: U2.6 (I/O1), U7.25 (GPIO19/USB_D-)
/2USB_PRT_D+: J1.A6 (D+), J1.B6 (D+), R5.1
/2USB_PRT_D-: J1.A7 (D-), J1.B7 (D-), R4.1
/3v3.Sense: R10.1, R11.1, TP7.1, U7.7 (GPIO2)
/7SEG.CLK: C14.2, J2.7, R8.1, U3.18 (CLK)
/7SEG.DIO: C15.2, J2.9, R9.1, U3.17 (DIO)
/7SEG.GRID1: DISP1.12 (DIG1), U3.15 (GRID1)
/7SEG.GRID2: DISP1.8 (DIG2), U3.14 (GRID2)
/7SEG.GRID3: DISP1.7 (DIG3), U3.13 (GRID3)
/7SEG.K1: PB1.2 (B), PB3.2 (B), U3.19 (K1)
/7SEG.K2: PB2.2 (B), PB4.2 (B), U3.20 (K2)
/7SEG.SEG1: DISP1.9 (A), PB3.4 (D), PB4.4 (D), U3.2 (SEG1/KS1)
/7SEG.SEG2: DISP1.5 (B), PB2.4 (D), U3.3 (SEG2/KS2)
/7SEG.SEG3: DISP1.4 (C), PB1.4 (D), U3.4 (SEG3/KS3)
/7SEG.SEG4: DISP1.3 (D), U3.5 (SEG4/KS4)
/7SEG.SEG5: DISP1.1 (E), U3.6 (SEG5/KS5)
/7SEG.SEG6: DISP1.10 (F), U3.7 (SEG6/KS6)
/7SEG.SEG7: DISP1.2 (G), U3.8 (SEG7/KS7)
/7SEG.SEG8: DISP1.6 (DP), U3.9 (SEG8/KS8)
/CAM.D0: J3.10
/CAM.D1: J3.7
/CAM.D2: J3.6
/CAM.D3: J3.9
/CAM.D4: J3.11
/CAM.D5: J3.14
/CAM.D6: J2.12
/CAM.D7: J2.10
/CAM.HREF: J2.15
/CAM.MCLK: J2.14
/CAM.PCLK: J3.12
/CAM.SCL: J3.5
/CAM.SDA: J3.4
/CAM.VSYNC: J2.16
/ISEN.FLT: C1.1, U1.6 (FILTER)
/ISEN.VO: U1.7 (VOUT), U7.24 (GPIO18)
/LED.IR: R32.2, U7.10 (GPIO5)
/LED.OTH: R33.2, U7.11 (GPIO6)
/LED.RGB: D7.4 (DIN), TP51.1, U7.27 (GPIO21)
/LED.WH: R31.2, U7.9 (GPIO4)
/MIC.L: JP6.2 (C), U6.2 (LR)
/MIC.R: JP5.2 (C), U5.2 (LR)
/MIC.SCK: J3.17, U5.4 (SCK), U6.4 (SCK)
/MIC.SD: J3.19, U5.6 (SD), U6.6 (SD)
/MIC.WS: J3.20, U5.1 (WS), U6.1 (WS)
/MISC.OUT1: R21.2, TP40.1, U7.39 (GPIO34)
/MISC.OUT2: R20.2, TP41.1, U7.40 (GPIO35)
/MISC.OUT3: R19.2, TP42.1, U7.41 (GPIO36)
/PMU.SCK: TP43.1, U7.42 (GPIO37), U8.39 (SCK)
/PMU.SDA: TP44.1, U7.43 (GPIO38), U8.40 (SDA)
/PMU.Va1: C31.2, TP27.1, U8.18 (ALDO1)
/PMU.Va2: C32.2, TP28.1, U8.19 (ALDO2)
/PMU.Va3: C30.2, TP29.1, U8.16 (ALDO3)
/PMU.Va4: C29.2, TP30.1, U8.15 (ALDO4)
/PMU.Vb1: C27.2, TP21.1, U8.12 (BLDO1)
/PMU.Vb2: C28.2, TP22.1, U8.14 (BLDO2)
/PMU.Vcpu: C25.2, TP46.1, U8.10 (CPULDOS)
/PMU.Vd1: C33.2, TP23.1, U8.20 (DLDO1/DC1SW)
/PMU.Vd2: C26.2, TP24.1, U8.11 (DLDO2/DC4SW)
/PMU.Vo1: C48.2, L7.1, TP32.1, TST-R12.1, U8.22 (LX1)
/PMU.Vo1.Sense: TP39.1, U7.38 (GPIO33)
/PMU.Vo2: C47.2, L6.1, TP33.1, U8.26 (FB2)
/PMU.Vo3: C23.2, L3.1, TP34.1, U8.4 (FB3)
/PMU.Vo4: C24.2, L4.1, TP35.1, U8.8 (LX4)
/PMU.Vref: C22.2, TP47.1, U8.2 (VREF)
/PMU.Vsys: C17.2, C18.2, C19.2, C20.2, C50.2, C51.2, R13.2, R14.2, TP45.1, U8.6 (VIN3), U8.7 (VIN4), U8.13 (BLDOIN), U8.17 (ALDOIN), U8.23 (VIN1), U8.24 (VIN2), U8.34 (VSYS), U8.36 (VMID)
/RC.OTHR: J15.1, U7.51 (GPIO45)
/RC.OTHR2: J16.1, U7.52 (GPIO46)
/RC.PAN: J12.1, U7.45 (MTDO)
/RC.PWR: R26.2, U7.44 (MTCK)
/RC.ROT: J14.1, U7.48 (MTMS)
/RC.SERVO: J2.17
/RC.TILT: J13.1, U7.47 (MTDI)
/RC.VDD: J12.2, J13.2, J14.2, J15.2, J16.2, Q4.3 (D)
/RF2: C10.1, L1.1, U7.1 (LNA_IN)
/RF2-ANT: ANT1.1 (ANT), C11.1, L1.2
/RGB: J2.6
/SPK.BCLK: J3.16, U4.16 (BCLK)
/SPK.DIN: J3.15, U4.1 (DIN)
/SPK.LRCLK: JP7.2 (C), TP25.1, U4.14 (LRCLK)
/SPK.MIC: CN1.4, TP26.1
/SPK.MODE: R12.2, U4.4 (SD_MODE#)
/SPK.OutN: C41.2, CN1.1, J4.2, U4.10 (OUTN)
/SPK.OutP: C42.1, CN1.2, CN1.3, U4.9 (OUTP)
/SPK.OutPS: CN1.5, CN1.6, J4.1
/TEMP.DQ: U7.23 (GPIO17), U10.1 (DQ)
/U0RXD: J2.19, J6.2, U7.50 (U0RXD)
/U0TXD: J2.20, J6.1, U7.49 (U0TXD)
/USB_D+: J3.1
/USB_D-: J3.2
/V.SPK: C16.1, C21.1, JP7.1 (A), TST-R5.1, U4.7 (VDD), U4.8 (VDD)
/VDCDC5: C45.2, C46.2, L5.1, TP48.1, TST-R13.1, U8.32 (GPIO1/FB5/RTC/LDO2)
COM: BOOT1.3 (C), BT1.1, C1.2, C2.2, C3.2, C4.2, C5.2, C6.2, C7.1, C8.2, C9.1, C10.2, C11.2, C12.1, C13.2, C14.1, C15.1, C16.2, C17.1, C18.1, C19.1, C20.1, C21.2, C22.1, C23.1, C24.1, C25.1, C26.1, C27.1, C28.1, C29.1, C30.1, C31.1, C32.1, C33.1, C34.1, C35.2, C36.2, C37.2, C38.2, C39.1, C40.1, C41.1, C42.2, C43.1, C44.2, C45.1, C46.1, C47.1, C48.1, C49.1, C50.1, C51.1, C52.1, C53.2, C54.1, C55.1, C56.1, C57.1, D4.1 (C), D5.1 (C), D6.1 (C), D7.3 (GND), D8.1, D9.1 (C), J1.A12B1 (GND), J1.B12A1 (GND), J1.S1 (SHIELD), J2.3, J2.8, J2.13, J2.18, J3.3, J3.8, J3.13, J3.18, J5.2, J7.2, J8.2, J9.2, J10.2, J11.2, J12.3, J13.3, J14.3, J15.3, J16.3, J17.2, J18.2, J19.2, JP3.1 (A), JP5.3 (B), JP6.1 (A), JP7.3 (B), NTC1.1, PB5.3 (C), R2.2, R3.2, R7.1, R11.2, RST1.3 (C), U1.5 (GND), U2.2 (GND), U3.1 (GND), U4.3 (GND), U4.11 (GND), U4.15 (GND), U4.17 (EP), U5.3 (GND), U6.3 (GND), U7.57 (GND), U8.3 (GND), U8.41 (EP), U9.4 (GND), U10.4 (GND), Y1.2 (GND), Y1.4 (GND)
unnamed: C2.1, R1.1, Y1.1 (OSC)
unnamed: D1.2, J1.A9B4 (VBUS), J1.B9A4 (VBUS)
unnamed: D2.2, R13.1
unnamed: D3.2, R14.1
unnamed: D4.2 (A), R22.2
unnamed: D5.2 (A), R23.2
unnamed: D6.2 (A), R24.2
unnamed: C56.2, D7.2 (VDD), TST-R19.1
unnamed: D8.2, R35.2
unnamed: D9.2 (A), R34.2
unnamed: DISP1.11 (NC), TP2.1
unnamed: J5.1, U8.27 (VBACKUP)
unnamed: J7.1, NTC1.2, U8.31 (TS)
unnamed: BT1.2, C49.2, J8.1, U8.33 (BAT)
unnamed: J9.1, Q1.3 (D), R22.1
unnamed: J10.1, Q2.3 (D), R23.1
unnamed: J11.1, Q3.3 (D), R24.1
unnamed: J17.1, Q7.3 (D)
unnamed: J18.1, Q6.3 (D), R34.1
unnamed: J19.1, Q5.3 (D), R35.1
unnamed: JP1.2 (B), JP2.2 (B), JP3.2 (B), JP4.2 (B), U4.2 (GAIN_SLOT)
unnamed: JP2.1 (A), R6.2
unnamed: JP4.1 (A), R7.2
unnamed: JP5.1 (A), TST-R6.1
unnamed: JP6.3 (B), TST-R7.1
unnamed: L2.1, TP5.1, TST-R3.2
unnamed: PB5.1 (A), U8.30 (PWRON)
unnamed: Q1.1 (G), R16.2, R19.1
unnamed: Q1.2 (S), R16.1, TST-R14.1
unnamed: Q2.1 (G), R17.2, R20.1
unnamed: Q2.2 (S), R17.1, TST-R15.1
unnamed: Q3.1 (G), R18.2, R21.1
unnamed: Q3.2 (S), R18.1, TST-R16.1
unnamed: Q4.1 (G), R25.2, R26.1
unnamed: Q4.2 (S), R25.1, TST-R18.1
unnamed: Q5.1 (G), R28.2, R31.1
unnamed: Q5.2 (S), R28.1, TST-R20.1
unnamed: Q6.1 (G), R29.2, R32.1
unnamed: Q6.2 (S), R29.1, TST-R21.1
unnamed: Q7.1 (G), R30.2, R33.1
unnamed: Q7.2 (S), R30.1, TST-R22.2
unnamed: R4.2, U2.1 (I/O1)
unnamed: R5.2, U2.3 (I/O2)
unnamed: R12.1, TST-R4.2
unnamed: TP17.1, U4.5 (N.C.)
unnamed: TP18.1, U4.6 (N.C.)
unnamed: TP19.1, U4.13 (N.C.)
unnamed: TP20.1, U4.12 (N.C.)
unnamed: TST-R1.2, U2.5 (VBUS)
unnamed: TP3.1, U3.12 (GRID4)
unnamed: TP4.1, U3.11 (GRID5)
unnamed: TP1.1, U3.10 (GRID6)
unnamed: C7.2, C8.1, R8.2, R9.2, TST-R2.1, U3.16 (VDD)
unnamed: C39.2, TST-R9.1, U5.5 (VDD)
unnamed: C40.2, TST-R10.1, U6.5 (VDD)
unnamed: TP36.1, U7.28 (SPICS1)
unnamed: C34.2, C35.1, C36.1, C37.1, C38.1, TST-R8.1, U7.2 (VDD3P3), U7.3 (VDD3P3), U7.20 (VDD3P3_RTC), U7.55 (VDDA), U7.56 (VDDA)
unnamed: D2.1, U8.1 (CHGLED)
unnamed: L7.2, U8.21 (FB1)
unnamed: L4.2, U8.9 (FB4)
unnamed: TP31.1, U8.38 (IRQ)
unnamed: L6.2, U8.25 (LX2)
unnamed: L3.2, U8.5 (LX3)
unnamed: D3.1, U8.29 (PWROK)
unnamed: L5.2, U8.35 (SW)
unnamed: C44.1, TST-R11.1, U8.37 (VBUS)
unnamed: C43.2, U8.28 (VRTC)
unnamed: C54.2, TST-R17.2, U10.8 (VDD)
V-USB: J2.1
Vdrive: D1.1, TST-R1.1, TST-R11.2, U1.1 (IP+), U1.2 (IP+)
Vdrive2: JP1.1 (A), R6.1, TST-R2.2, TST-R4.1, TST-R5.2, TST-R6.2, TST-R9.2, TST-R13.2, TST-R14.2, TST-R15.2, TST-R16.2, TST-R18.2, TST-R20.2, TST-R21.2, TST-R22.1
Vsys_5V: C3.1, J2.2, U1.3 (IP-), U1.4 (IP-), U1.8 (VCC)

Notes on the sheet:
GPIO15
GPIO37
RF Voltage Filter
GPIO0
2GPIO18
Current Sense
RST Button
expected risky area -- camera connector pinout, is pin1 really pin 1 not 24? -- I2S microphones and amplifier, should they be the same lines like code suggests -- I2C, does this need pull up, or can internal pullup suffice? -- POE ethernet, complete unknown. Fingers crossed. TODO -- make office con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
2GPIO21
Boot Button
LIGHTS
RC SERVO'S
BATTERY PMU / GUAGE
GPIO21
Crystals
2GPIO2
2GPIO28
2GPIO17
ROTATE
MICROPHONES
GPIO46
2GPIO26
NTC wants to be TH11-3H103F while C3018545 is probably a close enough equiv.
NOR FLASH
GPIO36
GPIO34
Z=50R
2GPIO41
2GPIO27
2GPIO29
I2S CHANNEL LR = HI = RIGHT LR = LOW = LEFT
GPIO1
Mode: QuadSPI
2GPIO36
Z=(35+j10)R
2GPIO30
2GPIO44
PI Filter Antenna
GPIO20
GPIO3

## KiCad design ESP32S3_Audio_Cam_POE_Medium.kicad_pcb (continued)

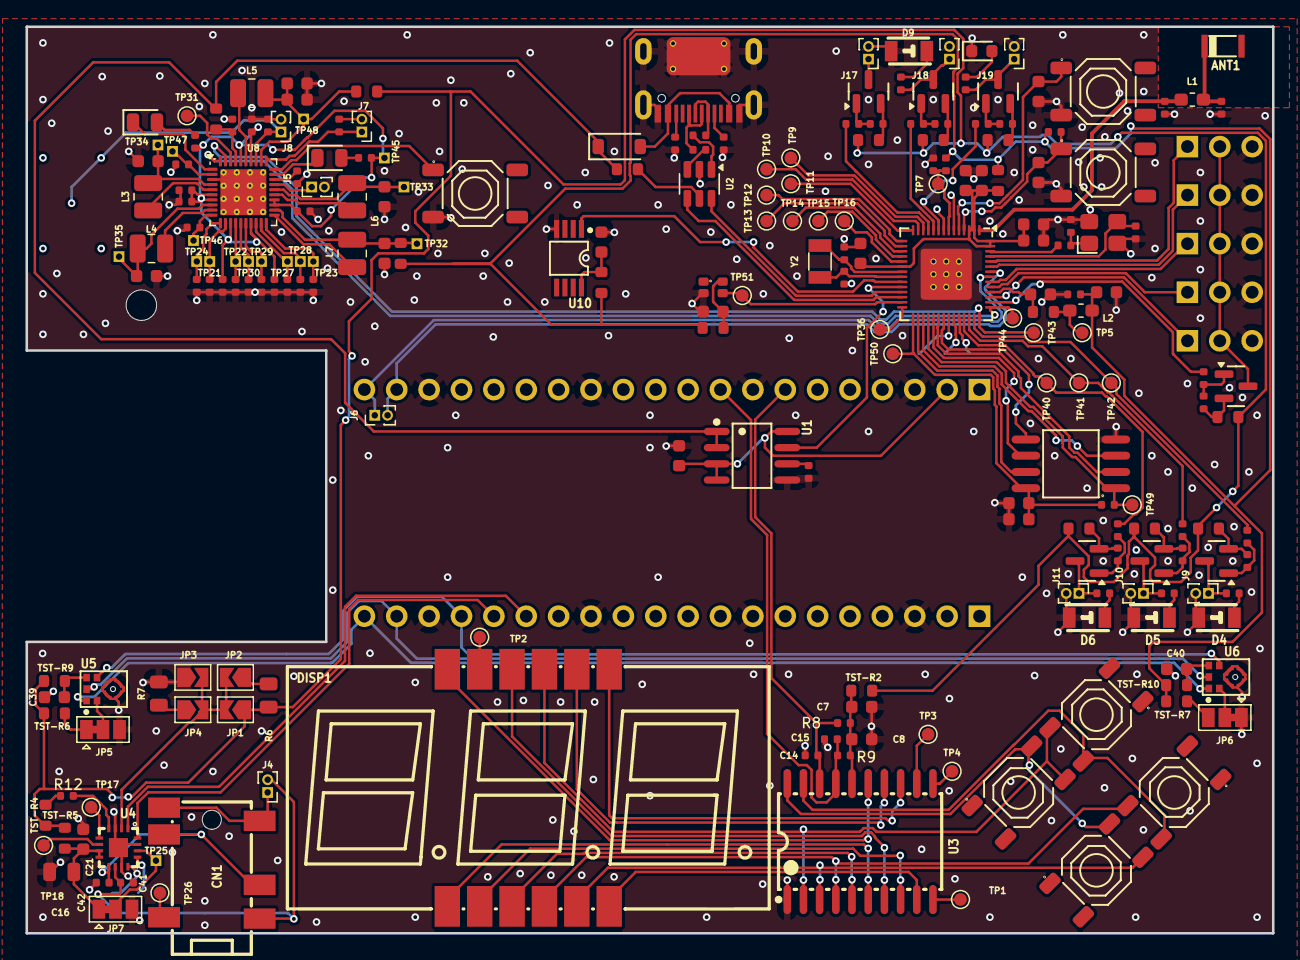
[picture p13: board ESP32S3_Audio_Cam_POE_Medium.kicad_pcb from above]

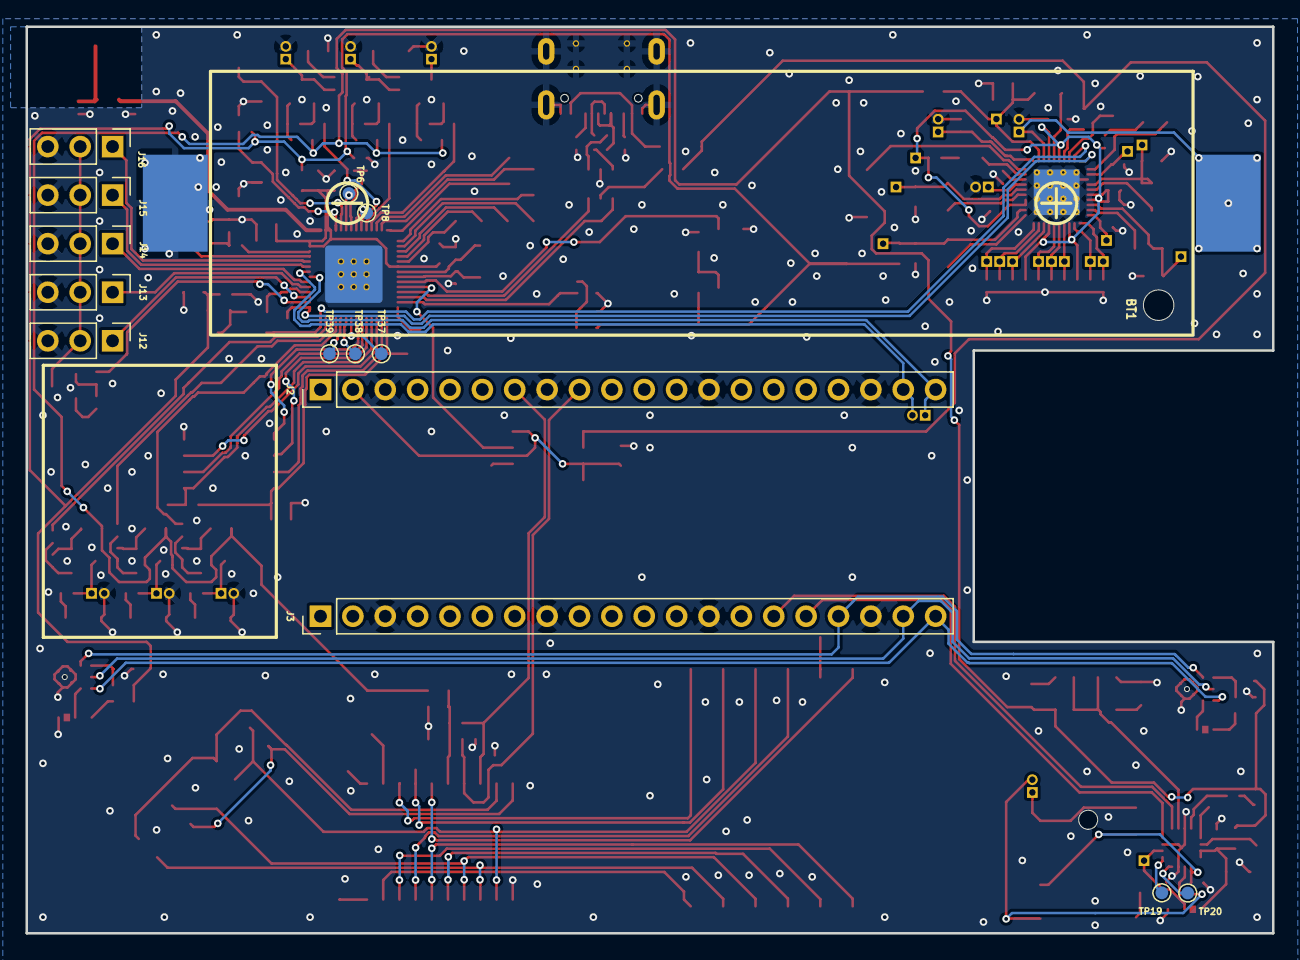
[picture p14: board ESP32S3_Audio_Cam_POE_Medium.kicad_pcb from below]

Board: 2 copper layers, 97.8 x 71.1 mm, 238 parts (15 on the bottom side), 175 nets.

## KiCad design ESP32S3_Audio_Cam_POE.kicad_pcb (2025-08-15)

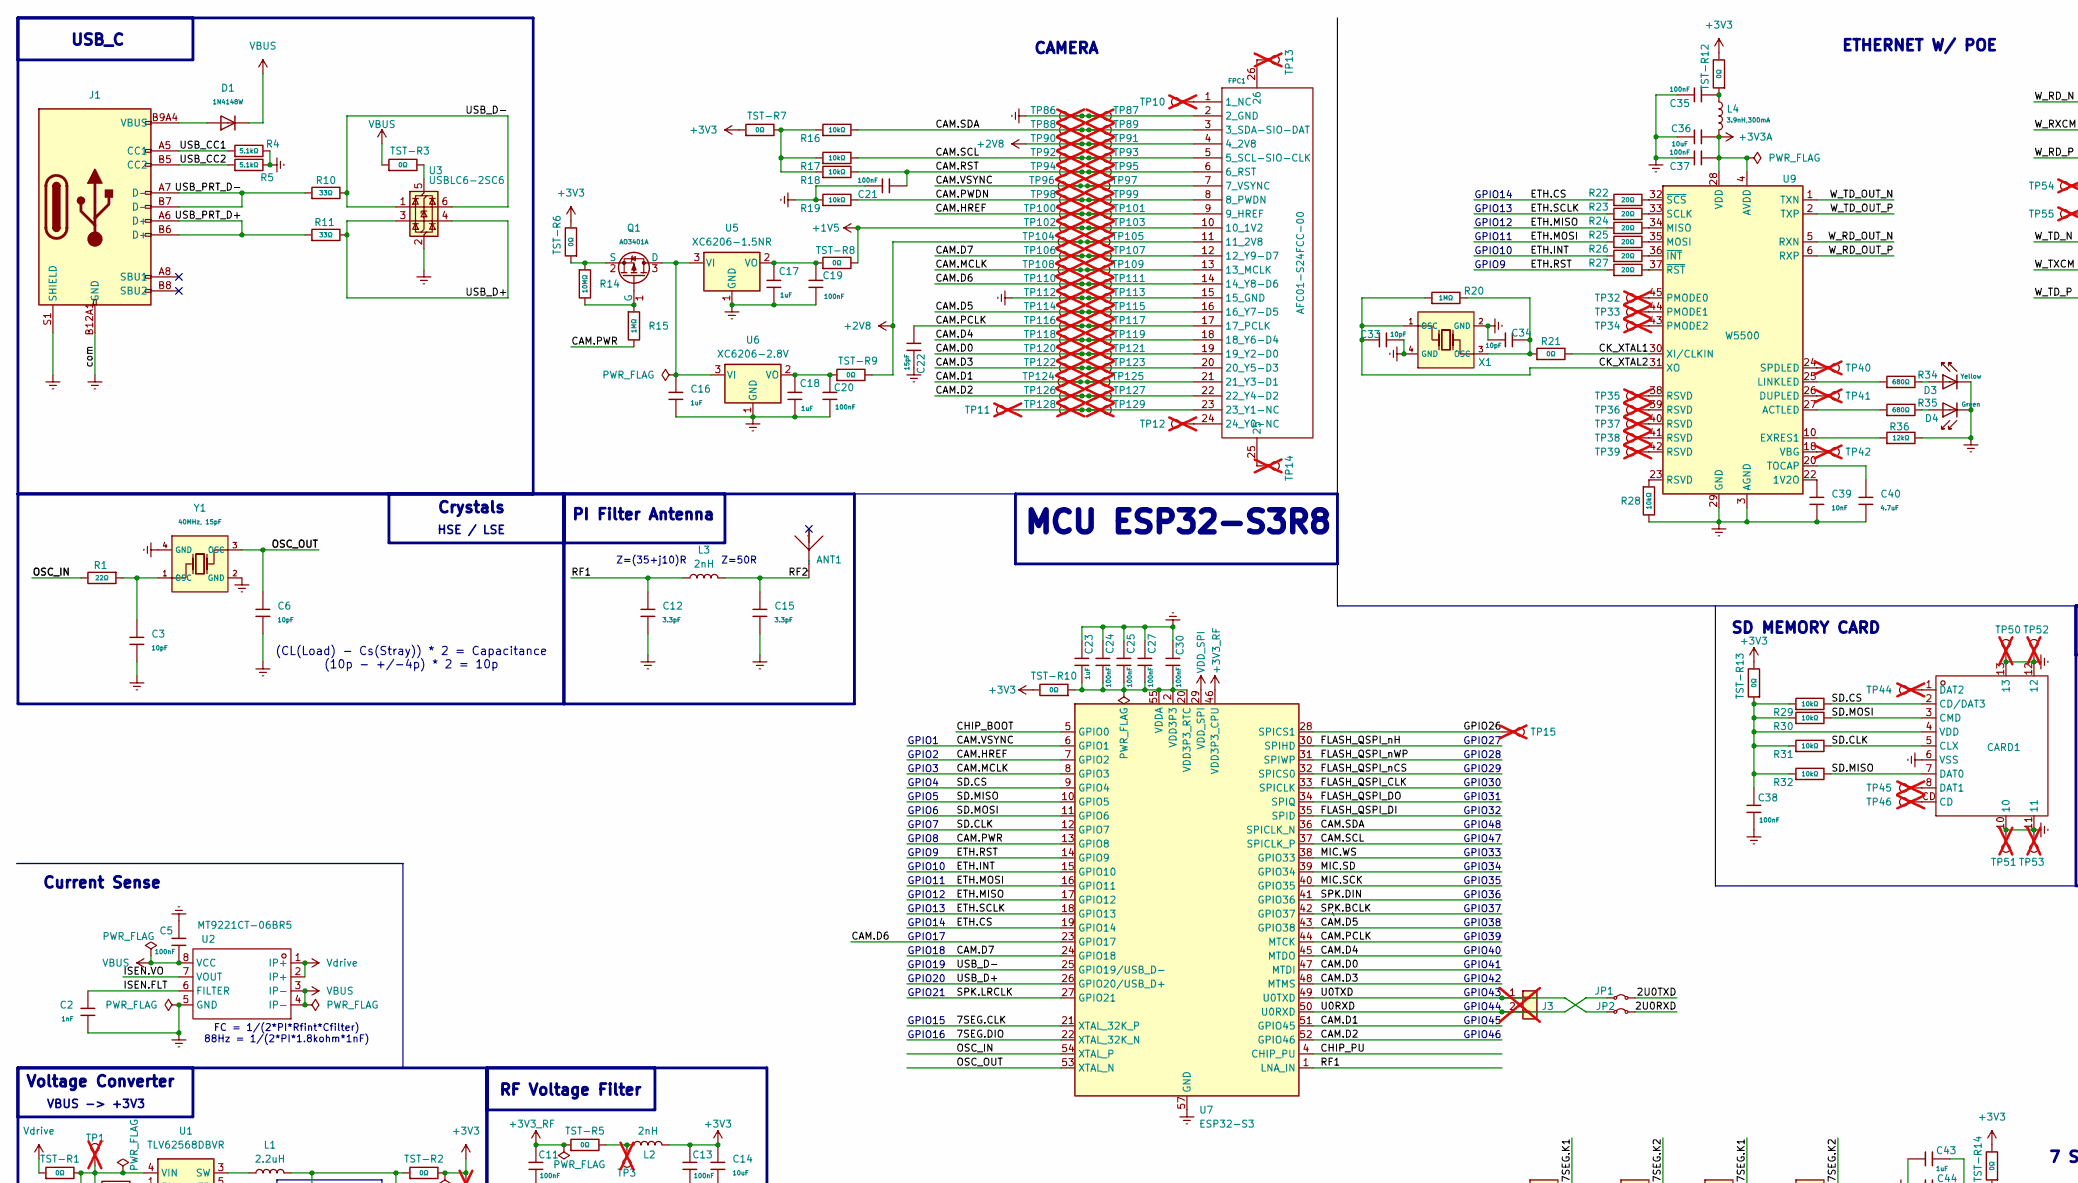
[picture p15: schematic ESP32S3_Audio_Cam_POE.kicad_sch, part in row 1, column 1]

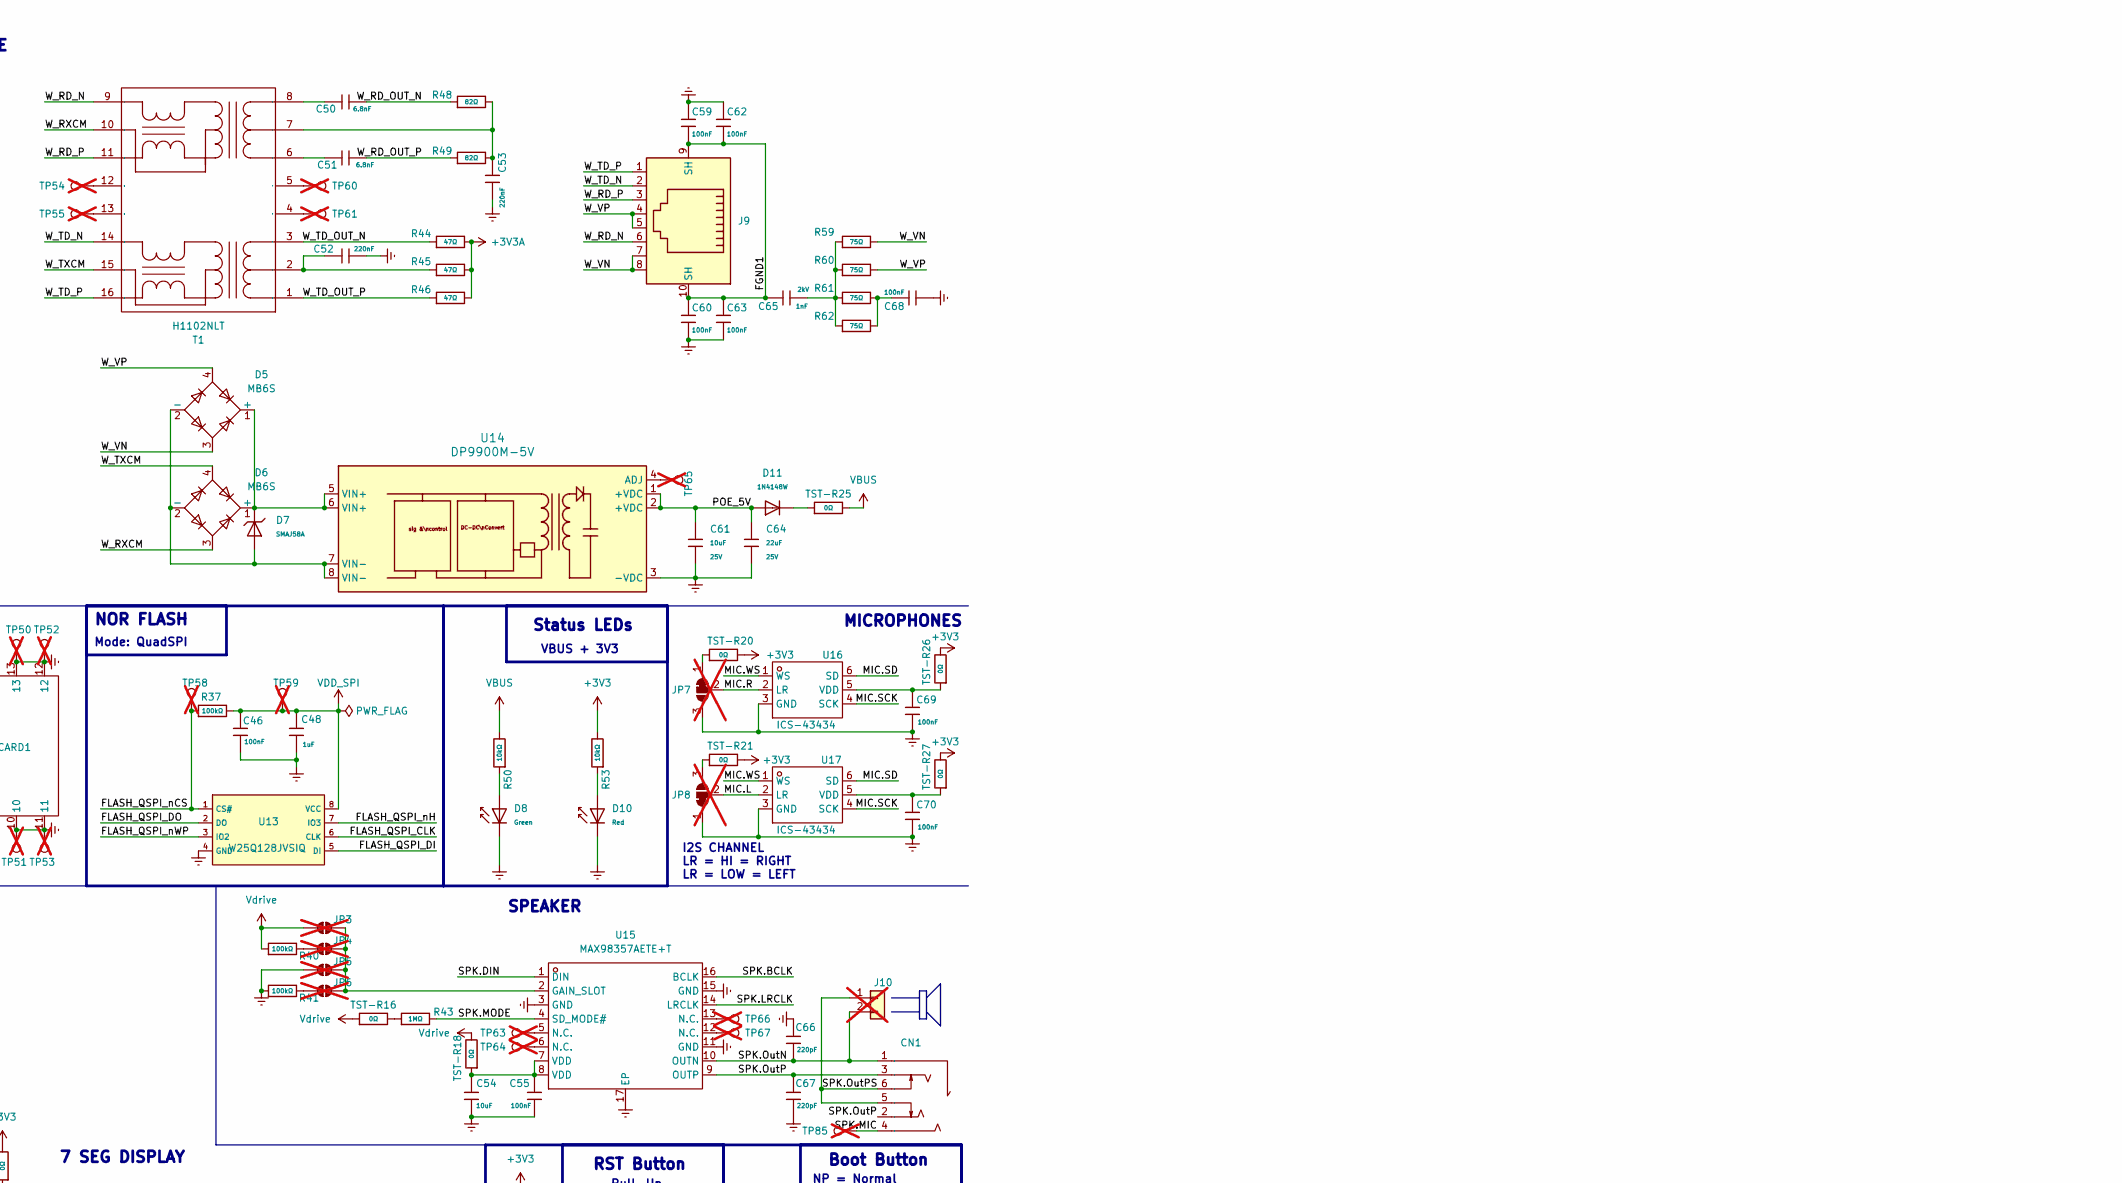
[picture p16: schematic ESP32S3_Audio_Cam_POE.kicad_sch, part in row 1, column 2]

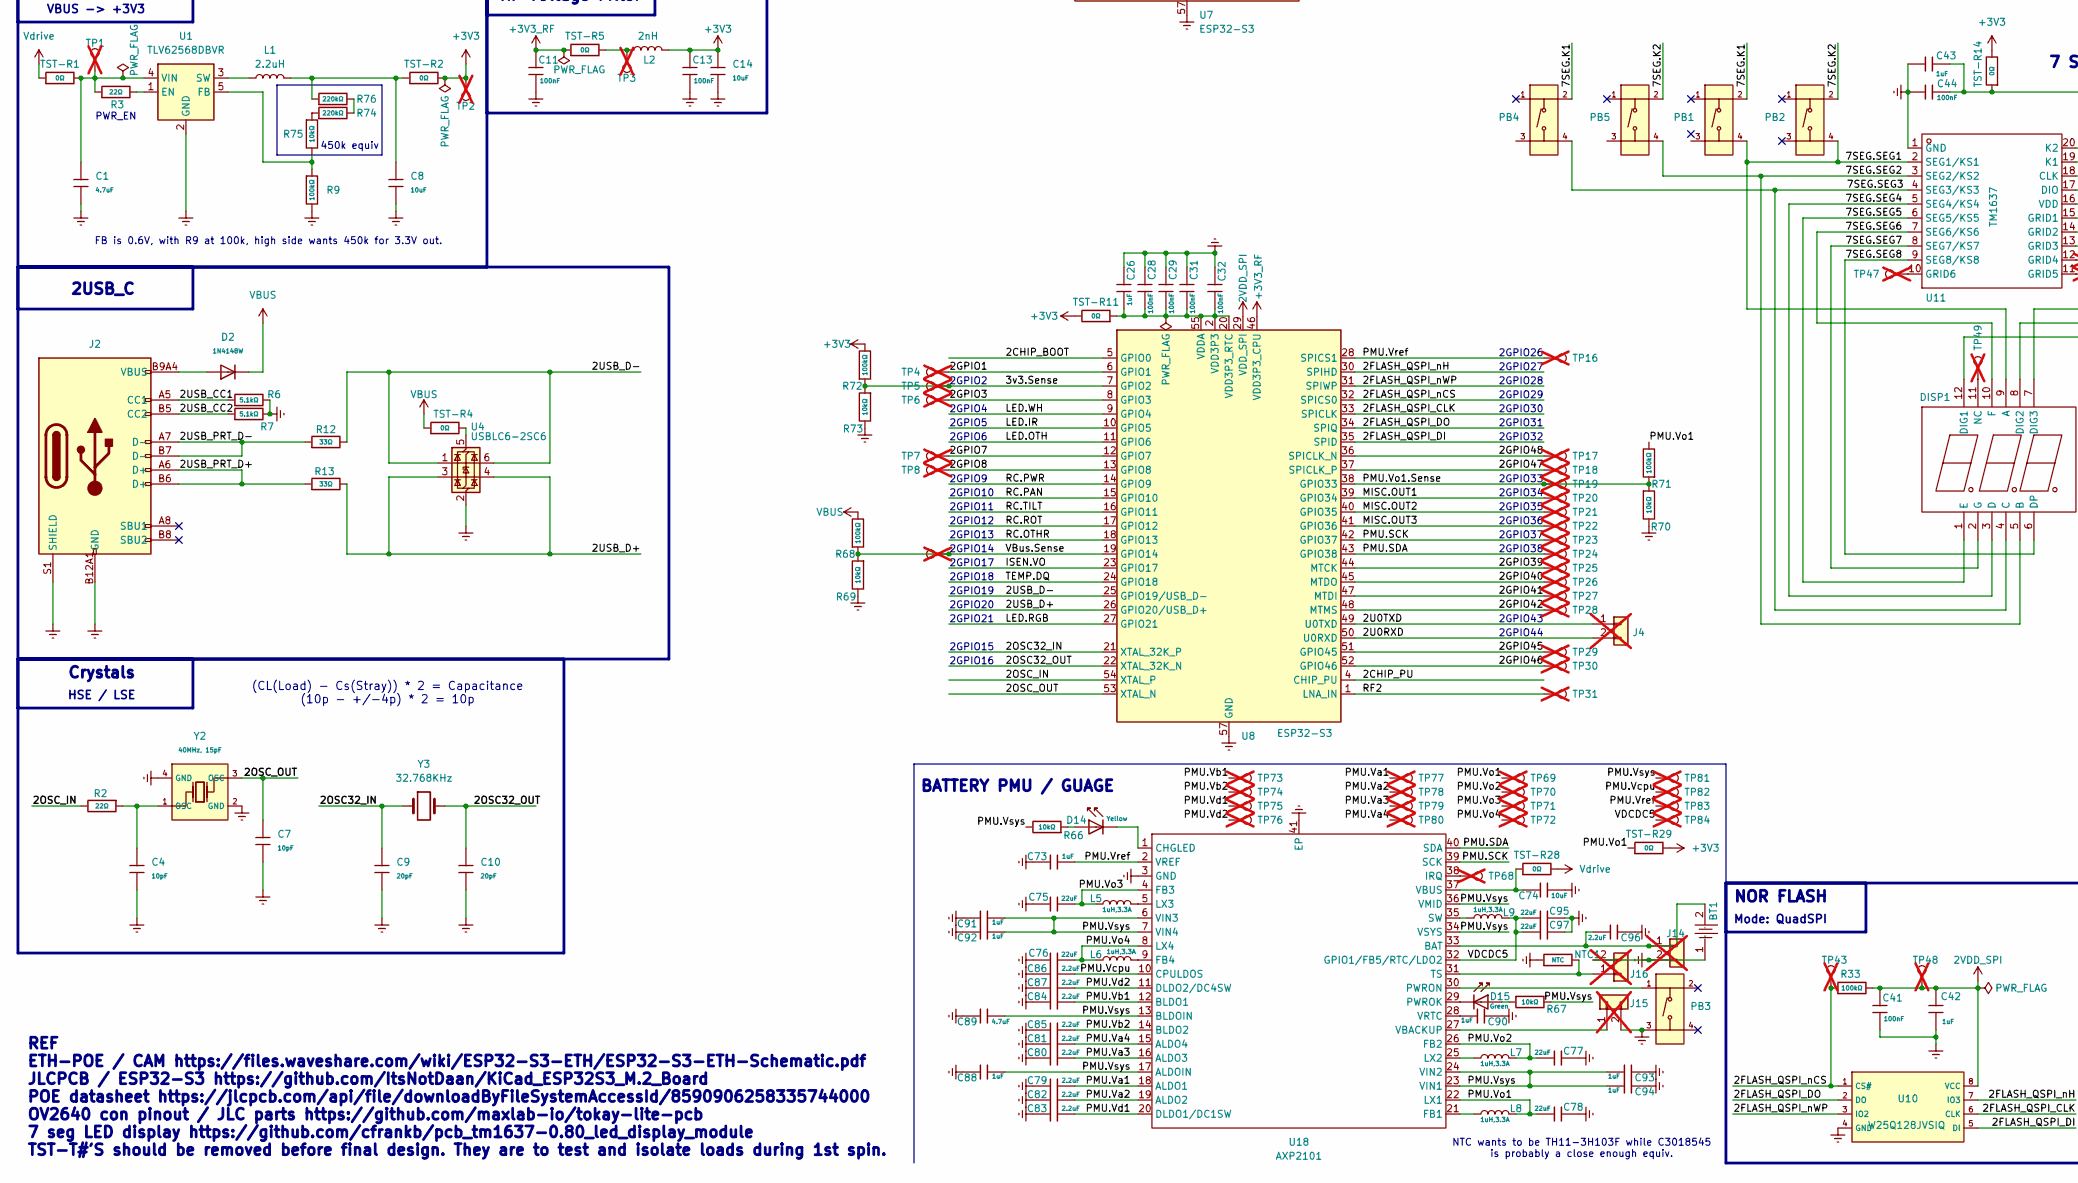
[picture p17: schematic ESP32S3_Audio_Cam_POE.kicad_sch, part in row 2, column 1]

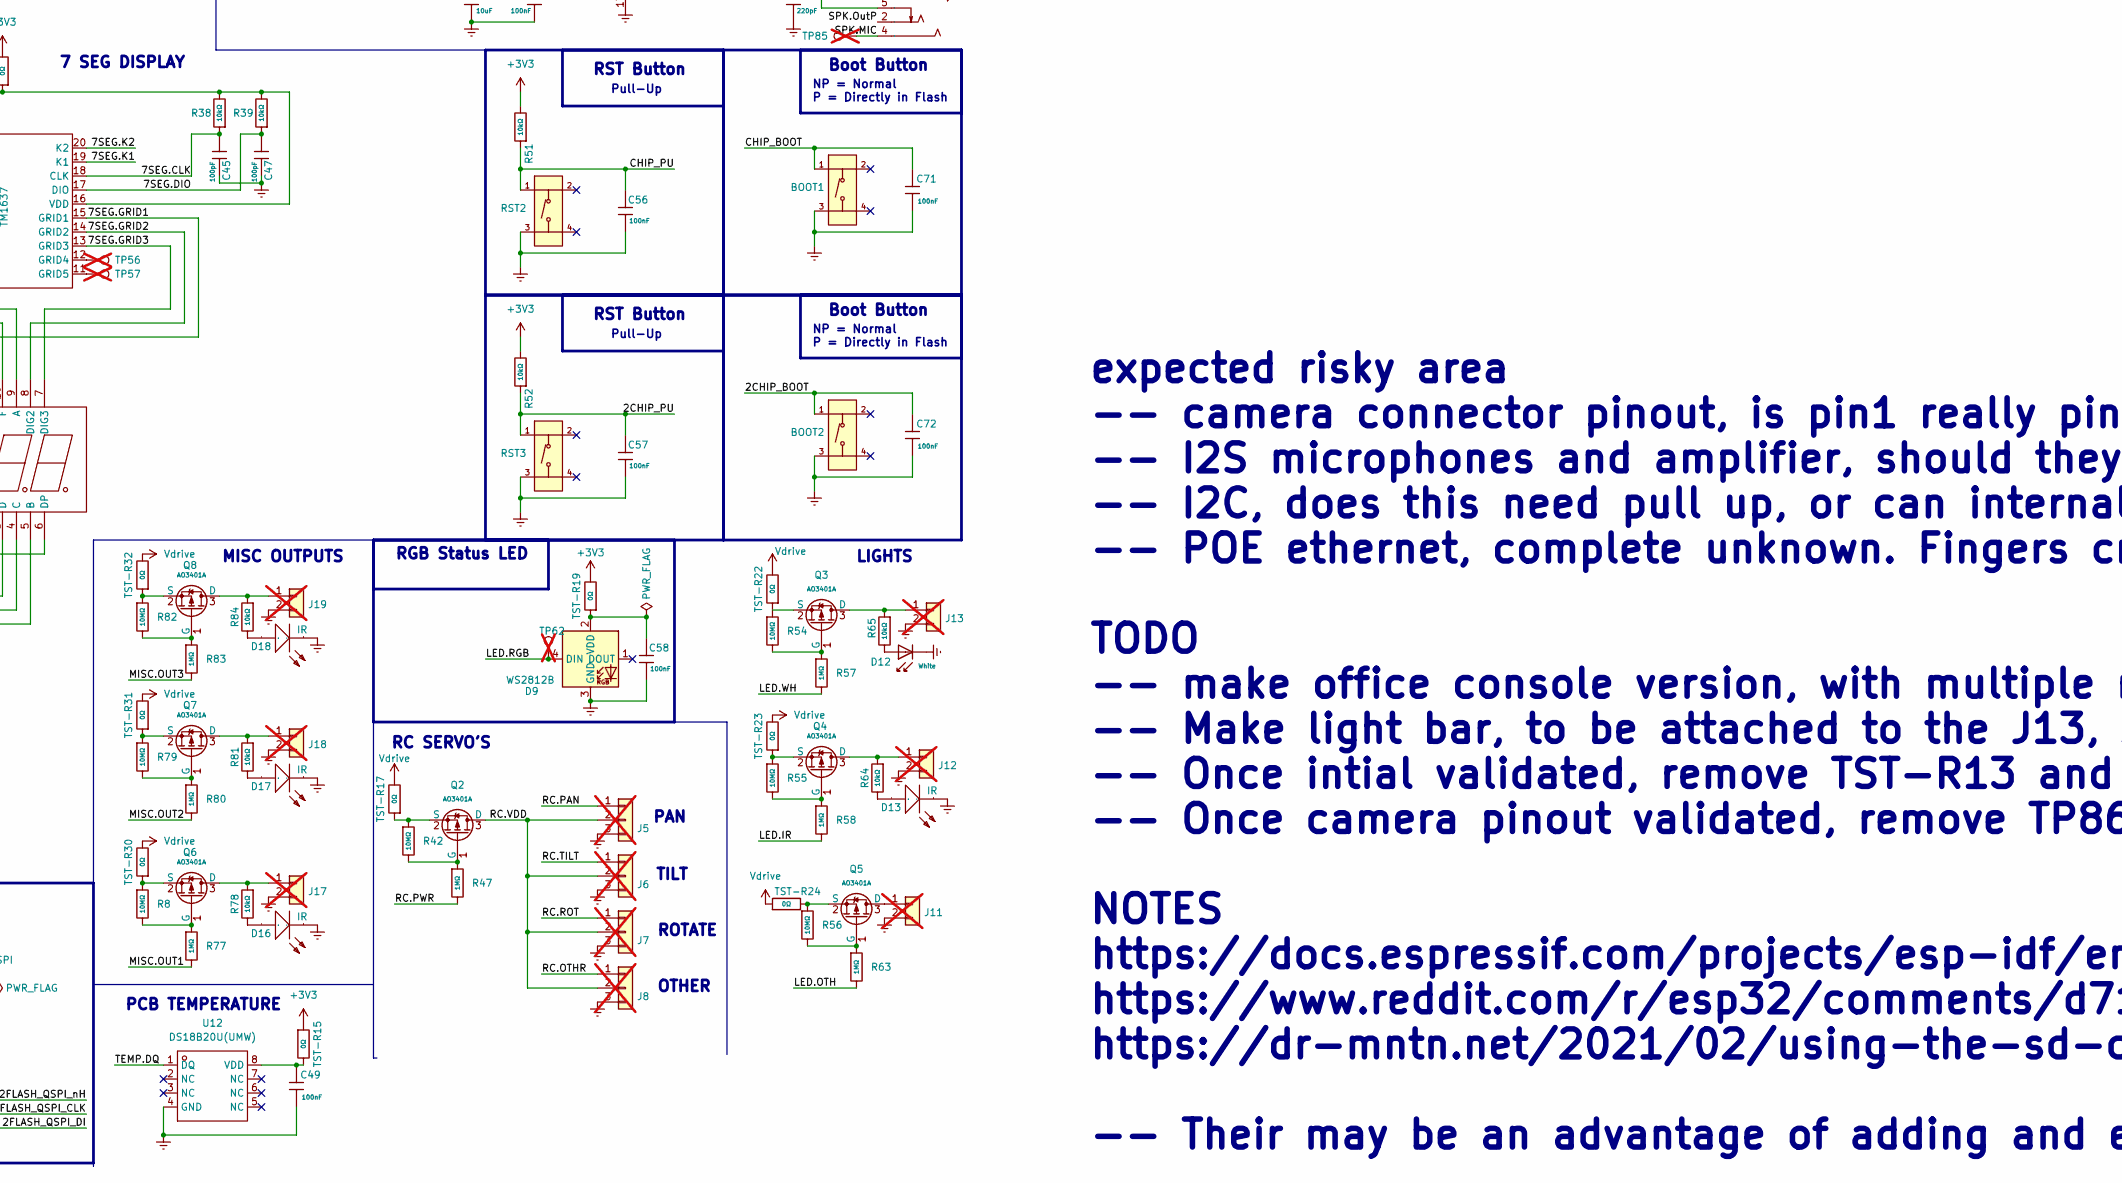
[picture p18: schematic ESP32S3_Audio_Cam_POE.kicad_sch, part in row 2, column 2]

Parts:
ANT1: KH-3216-H0209; ANT-SMD_L3.2-W1.6-KH-3216F245C04; Manufacturer_Part_Number KH-3216-H0209; LCSC PART # C2925417
BOOT1, BOOT2: Tactile Button, 160gf; SW-SMD_4P-L5.1-W5.1-P3.70-LS6.5-TL-2; Voltage Rating (Dc) 12V; Part TS-1187A-B-A-B; LCSC C318884
BT1: BH-18650-B1BA002; BATTERY-SMD_18650-1S-L77.1-W20.7-1; Manufacturer Part BH-18650-B1BA002; LCSC C2988620
C1: 4.7uF; C_0805; Voltage Rated 25V; Tolerance ±10%; Part CL21A475KAQNNNE; LCSC C1779
C2: 1nF; C_0402; Voltage Rated 50V; Tolerance ±10%; Part 0402B102K500NT; LCSC C1523
C3, C4, C6, C7, C33, C34: 10pF; C_0402; Voltage Rated 50V; Tolerance ±5%; Part CL05C100JB5NNNC; LCSC C32949
C5, C11, C13, C19, C20, C21, C24, C25, C27, C28, C29, C30, C31, C32, C35, C37, C38, C41, C44, C46, C49, C55, C56, C57, C58, C68, C69, C70, C71, C72: 100nF; C_0603; Voltage Rated 50V; Tolerance ±10%; Part CC0603KRX7R9BB104; LCSC C14663
C8, C14, C74: 10uF; C_0402; Voltage Rated 6.3V; Tolerance ±20%; Part CL05A106MQ5NUNC; LCSC C15525
C9, C10: 20pF; C_0402; Voltage Rated 50V; Tolerance ±5%; Part 0402CG200J500NT; LCSC C1554
C12, C15: 3.3pF; C_0402; Voltage Rated 50V; Part 0402CG3R3C500NT; LCSC C1565
C16, C17, C18, C23, C26, C42, C43, C48: 1uF; C_0603; Voltage Rated 50V; Tolerance ±10%; Part CL10A105KB8NNNC; LCSC C15849
C22: 15pF; C_0402; Voltage Rated 50V; Tolerance ±5%; Part 0402CG150J500NT; LCSC C1548
C36, C54: 10uF; C_0805; Voltage Rated 50V; Tolerance ±10%; Part GRM21BR61H106KE43L; LCSC C440198
C39: 10nF; C_0402; Voltage Rated 50V; Tolerance ±10%; Part CL05B103KB5NNNC; LCSC C15195
C40: 4.7uF; C_0603; Voltage Rated 16V; Tolerance ±10%; Part CL10A475KO8NNNC; LCSC C19666
C45, C47: 100pF; C_0402; Voltage Rated 50V; Tolerance ±5%; Part 0402CG101J500NT; LCSC C1546
C50, C51: 6.8nF; C_0603; Voltage Rated 50V; Tolerance ±10%; Part 0603B682K500NT; LCSC C1631
C52, C53: 220nF; C_0603; Voltage Rated 25V; Tolerance ±10%; Part CL10B224KA8NNNC; LCSC C21120
C59, C60, C62, C63: 100nF; C_0805; Voltage Rated 100V; Tolerance ±10%; Part CL21B104KCFNNNE; LCSC C28233
C61: 10uF; C_0805; Voltage Rated 25V; Tolerance ±10%; Part CL21A106KAYNNNE; LCSC C15850
C64: 22uF; C_0805; Voltage Rated 25V; Tolerance ±20%; Part CL21A226MAQNNNE; LCSC C45783
C65: 1nF; C_1206; Voltage Rated 2kV; Tolerance ±10%; Part 1206B102K202NT; LCSC C9196
C66, C67: 220pF; C_0402; Voltage Rated 50V; Tolerance ±10%; Part 0402B221K500NT; LCSC C1530
C73, C88, C90, C91, C92, C93, C94: 1uF; C_0402; Voltage Rated 25V; Tolerance ±10%; Part CL05A105KA5NQNC; LCSC C52923
C75, C76, C77, C78, C95, C97: 22uF; C_0603; Voltage Rated 6.3V; Tolerance ±20%; Part CL10A226MQ8NRNC; LCSC C59461
C79, C80, C81, C82, C83, C84, C85, C86, C87, C96: 2.2uF; C_0402; Voltage Rated 6.3V; Tolerance ±20%; Part CL05A225MQ5NSNC; LCSC C12530
C89: 4.7uF; C_0402; Voltage Rated 10V; Tolerance ±20%; Part CL05A475MP5NRNC; LCSC C23733
CARD1: TF PUSH; TF-PUSH-SD-CARD_C393941; LCSC C393941
CN1: PJ-316C-6A; SMD_3.5mm_Audio_Connectors_(Headphones)_C707223; Manufacturer Part PJ-316C-6A; LCSC C707223
D1, D2, D11: 1N4148W; D_SOD-123; Forward Voltage (Vf@If) 1V@50mA; Reverse Voltage (Vr) 75V; Part 1N4148W; LCSC C81598
D3, D14: Yellow; D_0805; Part KT-0805Y; LCSC C2296
D4, D8, D15: Green; D_0805; Part KT-0805G; LCSC C2297
D5, D6: MB6S; MB6S-C82584; LCSC C82584
D7: SMAJ58A; D_SMA; Part SMAJ58A; LCSC C19077554
D9: WS2812B; LED-SMD_4P-L1.6-W1.5_XL-1615RGBC-WS2812B; LCSC C5349954
D10: Red; D_0603; Part KT-0603R; LCSC C2286
D12: White; D_0603; Part KT-0603W; LCSC C2290
D13, D16, D17, D18: IR; IR-LED_C131280; LCSC C131280
DISP1: SLS0563DRA1GD; 3x7-seg_LED-RED_C2913084; LCSC C2913084
FPC1: AFC01-S24FCC-00; OV2640_connector_AFC01-S24FCC-00; Manufacturer Part AFC01-S24FCC-00; LCSC C262276
J1, J2: Connector, USB-TYPE-C-16P; TYPE-C-SMD_HX-TYPE-C-16PIN; LCSC C2927039
J3, J4, J10, J11, J12, J13, J14, J15, J16, J17, J18, J19: Conn_01x02; PinHeader_1x02_P1.00mm_Vertical; not fitted
J5, J6, J7, J8: Conn_01x03; PinHeader_1x03_P2.54mm_Vertical; not fitted
J9: HC-RJ45-055-4_8P8C_Shielded; HC-RJ45-055-4_C3000211; LCSC C3000211
JP1, JP2: Jumper_2_Small_Bridged; SolderJumper-2_P1.3mm_Bridged_RoundedPad1.0x1.5mm
JP3, JP4, JP5, JP6: SolderJumper_2_Open; SolderJumper-2_P1.3mm_Open_TrianglePad1.0x1.5mm; not fitted
JP7, JP8: SolderJumper_3_Bridged12; SolderJumper-3_P1.3mm_Bridged12_Pad1.0x1.5mm; not fitted
L1: 2.2uH; L_Wurth_WE-LQSH-4020; LCSC PART # C135262
L2, L3: 2nH; L_0603_1608Metric_Pad1.05x0.95mm_HandSolder; LCSC PART # C29682
L4: 3.9nH,300mA; L_0402; Part SDCL1005C3N9STDF; LCSC C14033
L5, L6, L7, L8, L9: 1uH,3.3A; L_1008_2520Metric; Tolerance ±10%; Part SDFL2012Q1R0KTF; LCSC C435392
NTC1: NTC; R_0402; Overload Voltage (Max) 50V; Tolerance ±1%; Part 0402WGF1002TCE; LCSC C3018545
PB1, PB2, PB3, PB4, PB5: Tactile Button, 160gf; SW-SMD_4P-L5.1-W5.1-P3.70-LS6.5-TL-2; Voltage Rating (Dc) 12V; Part TS-1187A-B-A-B; LCSC C318884
Q1, Q2, Q3, Q4, Q5, Q6, Q7, Q8: AO3401A; Q_SOT-23; Part AO3401A; LCSC C15127
R1, R2, R3: 22Ω; R_0402; Overload Voltage (Max) 50V; Tolerance ±1%; Part 0402WGF220JTCE; LCSC C25092
R4, R5, R6, R7: 5.1kΩ; R_0402; Overload Voltage (Max) 50V; Tolerance ±1%; Part 0402WGF5101TCE; LCSC C25905
R8, R14, R42, R54, R55, R56, R79, R82: 10MΩ; R_0402; Overload Voltage (Max) 50V; Tolerance ±1%; Part 0402WGF1005TCE; LCSC C26082
R9, R33, R37, R68, R71, R72: 100kΩ; R_0402; Overload Voltage (Max) 50V; Tolerance ±1%; Part 0402WGF1003TCE; LCSC C25741
R10, R11, R12, R13: 33Ω; R_0402; Overload Voltage (Max) 50V; Tolerance ±1%; Part 0402WGF330JTCE; LCSC C25105
R15, R20, R43, R47, R57, R58, R63, R77, R80, R83: 1MΩ; R_0402; Overload Voltage (Max) 50V; Tolerance ±1%; Part 0402WGF1004TCE; LCSC C26083
R16, R17, R18, R19, R28, R29, R30, R31, R32, R38, R39, R50, R51, R52, R53, R64, R65, R66, R67, R69, R70, R73, R75, R78, R81, R84: 10kΩ; R_0402; Overload Voltage (Max) 50V; Tolerance ±1%; Part 0402WGF1002TCE; LCSC C25744
R21: 0Ω; R_0402; Overload Voltage (Max) 50V; Tolerance ±1%; Part 0402WGF0000TCE; LCSC C17168
R22, R23, R24, R25, R26, R27: 20Ω; R_0603; Overload Voltage (Max) 75V; Tolerance ±1%; Part 0603WAF200JT5E; LCSC C22950
R34, R35: 680Ω; R_0402; Overload Voltage (Max) 50V; Tolerance ±1%; Part 0402WGF6800TCE; LCSC C25130
R36: 12kΩ; R_0603; Overload Voltage (Max) 75V; Tolerance ±1%; Part 0603WAF1202T5E; LCSC C22790
R40, R41: 100kΩ; R_0805; Overload Voltage (Max) 150V; Tolerance ±1%; Part 0805W8F1003T5E; LCSC C149504
R44, R45, R46: 47Ω; R_0603; Overload Voltage (Max) 75V; Tolerance ±1%; Part 0603WAF470JT5E; LCSC C23182
R48, R49: 82Ω; R_0603; Overload Voltage (Max) 75V; Tolerance ±1%; Part 0603WAF820JT5E; LCSC C23255
R59, R60, R61, R62: 75Ω; R_0603; Overload Voltage (Max) 75V; Tolerance ±1%; Part 0603WAF750JT5E; LCSC C4275
R74, R76: 220kΩ; R_0402; Overload Voltage (Max) 50V; Tolerance ±1%; Part 0402WGF2203TCE; LCSC C25767
RST2, RST3: Tactile Button, 160gf; SW-SMD_4P-L5.1-W5.1-P3.70-LS6.5-TL-2; Voltage Rating (Dc) 12V; Part TS-1187A-B-A-B; LCSC C318884
T1: H1102NLT; H1102NLT_C18584; LCSC Part Name H1102NLT
TP1, TP2, TP3, TP4, TP5, TP6, TP7, TP8, TP9, TP10, TP11, TP12, TP15, TP16, TP17, TP18, TP19, TP20, TP21, TP22, TP23, TP24, TP25, TP26, TP27, TP28, TP29, TP30, TP31, TP32, TP33, TP34, TP35, TP36, TP37, TP38, TP39, TP40, TP41, TP42, TP43, TP44, TP45, TP46, TP47, TP48, TP49, TP54, TP55, TP56, TP57, TP58, TP59, TP60, TP61, TP62, TP63, TP64, TP65, TP66, TP67, TP68, TP85: TestPoint; TestPoint_Pad_D1.0mm; not fitted
TP13, TP14, TP50, TP51, TP52, TP53: TestPoint; TestPoint_Plated_Hole_D2.0mm; not fitted
TP69, TP70, TP71, TP72, TP73, TP74, TP75, TP76, TP77, TP78, TP79, TP80, TP81, TP82, TP83, TP84, TP86, TP87, TP88, TP89, TP90, TP91, TP92, TP93, TP94, TP95, TP96, TP97, TP98, TP99, TP100, TP101, TP102, TP103, TP104, TP105, TP106, TP107, TP108, TP109, TP110, TP111, TP112, TP113, TP114, TP115, TP116, TP117, TP118, TP119, TP120, TP121, TP122, TP123, TP124, TP125, TP126, TP127, TP128, TP129: TestPoint; PinHeader_1x01_P1.00mm_Vertical; not fitted
TST-R1, TST-R2, TST-R3, TST-R4, TST-R5, TST-R6, TST-R7, TST-R8, TST-R9, TST-R10, TST-R11, TST-R12, TST-R13, TST-R14, TST-R15, TST-R16, TST-R17, TST-R18, TST-R19, TST-R20, TST-R21, TST-R22, TST-R23, TST-R24, TST-R25, TST-R26, TST-R27, TST-R28, TST-R29, TST-R30, TST-R31, TST-R32: 0Ω; R_0603; Overload Voltage (Max) 75V; Tolerance ±1%; Part 0603WAF0000T5E; LCSC C21189
U1: TLV62568DBVR; SOT-23-5; Manufacturer_Part_Number TLV62568DBVR; LCSC PART # C163219
U2: MT9221CT-06BR5; Current-sensor_MT9221CT-06BR5_C879632; LCSC C879632
U3, U4: USBLC6-2SC6; SOT-23-6; Manufacturer_Part_Number USBLC6-2SC6; LCSC PART # C2827654
U5: XC6206-1.5NR; SOT-23-3; LCSC C2984869
U6: XC6206-2.8V; SOT-23-3; LCSC C41424780
U7, U8: ESP32-S3; QFN-56-1EP_7x7mm_P0.4mm_EP4x4mm_ThermalVias; LCSC C2913194
U9: W5500; LQFP-48_7x7mm_P0.5mm; LCSC PART # C32843
U10, U13: W25Q128JVSIQ; SOIC-8_L5.3-W5.3-P1.27-LS8.0-BL; Part W25Q128JVSIQ; LCSC PART # C97521
U11: TM1637; digital tube drivers_c2962580; LCSC C2962580
U12: DS18B20U(UMW); DS18B20_C695836; LCSC C695836
U14: DP9900M-5V; DP9900M_C5380106; LCSC PART # C5380106
U15: MAX98357AETE+T; MAX98357AETE+T_C910544; Manufacturer Part MAX98357AETE+T
U16, U17: ICS-43434; ICS-43434_C5656610; LCSC C5656610
U18: AXP2101; QFN-40-1EP_5x5mm_P0.4mm_EP3.6x3.6mm_ThermalVias; LCSC C3036461
X1: X322525MOB4SI; OSC-SMD_4P-L3.2-W2.5-BL; Frequency Tolerance ±10ppm; Part X322525MOB4SI; LCSC C9006
Y1, Y2: 40MHz, 15pF; OSC-SMD_4P-L3.2-W2.5-BL_SIT8008BI; PartID X322540MPB4SI; LCSC C9010
Y3: 32.768KHz; Crystal_SMD_3215-2Pin_3.2x1.5mm; Manufacturer_Part_Number DST310S 32.768KHz; LCSC PART # C97604

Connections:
2VDD_SPI: C41.2, C42.1, R33.2, TP48.1, U8.29 (VDD_SPI), U10.8 (VCC)
+1V5: FPC1.10 (10_1V2), TP102.1, TP103.1, TST-R8.2
+2V8: FPC1.4 (4_2V8), FPC1.11 (11_2V8), TP90.1, TP91.1, TP104.1, TP105.1, TST-R9.2
+3V3: C13.2, C14.1, L2.2, R51.2, R52.2, R53.2, R72.2, TP2.1, TST-R2.2, TST-R6.2, TST-R7.1, TST-R10.2, TST-R11.2, TST-R12.2, TST-R13.2, TST-R14.2, TST-R15.1, TST-R19.2, TST-R20.2, TST-R21.2, TST-R26.2, TST-R27.2, TST-R29.2
+3V3A: C36.2, C37.2, L4.1, R44.2, R45.2, R46.2, U9.4 (AVDD), U9.8 (AVDD), U9.11 (AVDD), U9.15 (AVDD), U9.17 (AVDD), U9.21 (AVDD), U9.28 (VDD)
+3V3_RF: C11.2, TST-R5.1, U7.46 (VDD3P3_CPU), U8.46 (VDD3P3_CPU)
/2CHIP_BOOT: BOOT2.1 (A), C72.2, U8.5 (GPIO0)
/2CHIP_PU: C57.2, R52.1, RST3.1 (A), U8.4 (CHIP_PU)
/2FLASH_QSPI_CLK: U8.33 (SPICLK), U10.6 (CLK)
/2FLASH_QSPI_DI: U8.35 (SPID), U10.5 (DI)
/2FLASH_QSPI_DO: U8.34 (SPIQ), U10.2 (DO)
/2FLASH_QSPI_nCS: R33.1, TP43.1, U8.32 (SPICS0), U10.1 (CS#)
/2FLASH_QSPI_nH: U8.30 (SPIHD), U10.7 (IO3)
/2FLASH_QSPI_nWP: U8.31 (SPIWP), U10.3 (IO2)
/2GPIO1: TP4.1, U8.6 (GPIO1)
/2GPIO3: TP6.1, U8.8 (GPIO3)
/2GPIO7: TP7.1, U8.12 (GPIO7)
/2GPIO8: TP8.1, U8.13 (GPIO8)
/2GPIO39: TP25.1, U8.44 (MTCK)
/2GPIO40: TP26.1, U8.45 (MTDO)
/2GPIO41: TP27.1, U8.47 (MTDI)
/2GPIO42: TP28.1, U8.48 (MTMS)
/2GPIO45: TP29.1, U8.51 (GPIO45)
/2GPIO46: TP30.1, U8.52 (GPIO46)
/2GPIO47: TP18.1, U8.37 (SPICLK_P)
/2GPIO48: TP17.1, U8.36 (SPICLK_N)
/2OSC32_IN: C9.1, U8.21 (XTAL_32K_P), Y3.1
/2OSC32_OUT: C10.1, U8.22 (XTAL_32K_N), Y3.2
/2OSC_IN: R2.2, U8.54 (XTAL_P)
/2OSC_OUT: C7.1, U8.53 (XTAL_N), Y2.3 (OSC)
/2U0RXD: J4.2, JP2.2 (B), U8.50 (U0RXD)
/2U0TXD: J4.1, JP1.2 (B), U8.49 (U0TXD)
/2USB_CC1: J2.A5 (CC1), R6.1
/2USB_CC2: J2.B5 (CC2), R7.1
/2USB_D+: R13.2, U4.3 (I/O2), U4.4 (I/O2), U8.26 (GPIO20/USB_D+)
/2USB_D-: R12.2, U4.1 (I/O1), U4.6 (I/O1), U8.25 (GPIO19/USB_D-)
/2USB_PRT_D+: J2.A6 (D+), J2.B6 (D+), R13.1
/2USB_PRT_D-: J2.A7 (D-), J2.B7 (D-), R12.1
/3v3.Sense: R72.1, R73.1, TP5.1, U8.7 (GPIO2)
/7SEG.CLK: C45.2, R38.1, U7.21 (XTAL_32K_P), U11.18 (CLK)
/7SEG.DIO: C47.2, R39.1, U7.22 (XTAL_32K_N), U11.17 (DIO)
/7SEG.GRID1: DISP1.12 (DIG1), U11.15 (GRID1)
/7SEG.GRID2: DISP1.8 (DIG2), U11.14 (GRID2)
/7SEG.GRID3: DISP1.7 (DIG3), U11.13 (GRID3)
/7SEG.K1: PB1.2 (B), PB4.2 (B), U11.19 (K1)
/7SEG.K2: PB2.2 (B), PB5.2 (B), U11.20 (K2)
/7SEG.SEG1: DISP1.9 (A), PB1.4 (D), PB2.4 (D), U11.2 (SEG1/KS1)
/7SEG.SEG2: DISP1.5 (B), PB5.4 (D), U11.3 (SEG2/KS2)
/7SEG.SEG3: DISP1.4 (C), PB4.4 (D), U11.4 (SEG3/KS3)
/7SEG.SEG4: DISP1.3 (D), U11.5 (SEG4/KS4)
/7SEG.SEG5: DISP1.1 (E), U11.6 (SEG5/KS5)
/7SEG.SEG6: DISP1.10 (F), U11.7 (SEG6/KS6)
/7SEG.SEG7: DISP1.2 (G), U11.8 (SEG7/KS7)
/7SEG.SEG8: DISP1.6 (DP), U11.9 (SEG8/KS8)
/CAM.D0: FPC1.19 (19_Y2-D0), TP120.1, TP121.1, U7.47 (MTDI)
/CAM.D1: FPC1.21 (21_Y3-D1), TP124.1, TP125.1, U7.51 (GPIO45)
/CAM.D2: FPC1.22 (22_Y4-D2), TP126.1, TP127.1, U7.52 (GPIO46)
/CAM.D3: FPC1.20 (20_Y5-D3), TP122.1, TP123.1, U7.48 (MTMS)
/CAM.D4: FPC1.18 (18_Y6-D4), TP118.1, TP119.1, U7.45 (MTDO)
/CAM.D5: FPC1.16 (16_Y7-D5), TP114.1, TP115.1, U7.43 (GPIO38)
/CAM.D6: FPC1.14 (14_Y8-D6), TP110.1, TP111.1, U7.23 (GPIO17)
/CAM.D7: FPC1.12 (12_Y9-D7), TP106.1, TP107.1, U7.24 (GPIO18)
/CAM.HREF: FPC1.9 (9_HREF), TP100.1, TP101.1, U7.7 (GPIO2)
/CAM.MCLK: FPC1.13 (13_MCLK), TP108.1, TP109.1, U7.8 (GPIO3)
/CAM.PCLK: C22.2, FPC1.17 (17_PCLK), TP116.1, TP117.1, U7.44 (MTCK)
/CAM.PWDN: FPC1.8 (8_PWDN), R19.2, TP98.1, TP99.1
/CAM.PWR: R15.2, U7.13 (GPIO8)
/CAM.RST: C21.2, FPC1.6 (6_RST), R18.2, TP94.1, TP95.1
/CAM.SCL: FPC1.5 (5_SCL-SIO-CLK), R17.2, TP92.1, TP93.1, U7.37 (SPICLK_P)
/CAM.SDA: FPC1.3 (3_SDA-SIO-DAT), R16.2, TP88.1, TP89.1, U7.36 (SPICLK_N)
/CAM.VSYNC: FPC1.7 (7_VSYNC), TP96.1, TP97.1, U7.6 (GPIO1)
/CHIP_BOOT: BOOT1.1 (A), C71.2, U7.5 (GPIO0)
/CHIP_PU: C56.2, R51.1, RST2.1 (A), U7.4 (CHIP_PU)
/CK_XTAL1: R21.2, U9.30 (XI/CLKIN)
/CK_XTAL2: C33.1, R20.1, U9.31 (XO), X1.1 (OSC)
/ETH.CS: R22.1, U7.19 (GPIO14)
/ETH.INT: R26.1, U7.15 (GPIO10)
/ETH.MISO: R24.1, U7.17 (GPIO12)
/ETH.MOSI: R25.1, U7.16 (GPIO11)
/ETH.RST: R27.1, U7.14 (GPIO9)
/ETH.SCLK: R23.1, U7.18 (GPIO13)
/FGND1: C59.2, C60.1, C62.2, C63.1, C65.1, J9.9 (SH), J9.10 (SH)
/FLASH_QSPI_CLK: U7.33 (SPICLK), U13.6 (CLK)
/FLASH_QSPI_DI: U7.35 (SPID), U13.5 (DI)
/FLASH_QSPI_DO: U7.34 (SPIQ), U13.2 (DO)
/FLASH_QSPI_nCS: R37.1, TP58.1, U7.32 (SPICS0), U13.1 (CS#)
/FLASH_QSPI_nH: U7.30 (SPIHD), U13.7 (IO3)
/FLASH_QSPI_nWP: U7.31 (SPIWP), U13.3 (IO2)
/GPIO26: TP15.1, U7.28 (SPICS1)
/ISEN.FLT: C2.1, U2.6 (FILTER)
/ISEN.VO: U2.7 (VOUT), U8.23 (GPIO17)
/LED.IR: R58.2, U8.10 (GPIO5)
/LED.OTH: R63.2, U8.11 (GPIO6)
/LED.RGB: D9.4 (DIN), TP62.1, U8.27 (GPIO21)
/LED.WH: R57.2, U8.9 (GPIO4)
/MIC.L: JP8.2 (C), U17.2 (LR)
/MIC.R: JP7.2 (C), U16.2 (LR)
/MIC.SCK: U7.40 (GPIO35), U16.4 (SCK), U17.4 (SCK)
/MIC.SD: U7.39 (GPIO34), U16.6 (SD), U17.6 (SD)
/MIC.WS: U7.38 (GPIO33), U16.1 (WS), U17.1 (WS)
/MISC.OUT1: R77.2, TP20.1, U8.39 (GPIO34)
/MISC.OUT2: R80.2, TP21.1, U8.40 (GPIO35)
/MISC.OUT3: R83.2, TP22.1, U8.41 (GPIO36)
/OSC_IN: R1.2, U7.54 (XTAL_P)
/OSC_OUT: C6.1, U7.53 (XTAL_N), Y1.3 (OSC)
/PMU.SCK: TP23.1, U8.42 (GPIO37), U18.39 (SCK)
/PMU.SDA: TP24.1, U8.43 (GPIO38), U18.40 (SDA)
/PMU.Va1: C79.2, TP77.1, U18.18 (ALDO1)
/PMU.Va2: C82.2, TP78.1, U18.19 (ALDO2)
/PMU.Va3: C80.2, TP79.1, U18.16 (ALDO3)
/PMU.Va4: C81.2, TP80.1, U18.15 (ALDO4)
/PMU.Vb1: C84.2, TP73.1, U18.12 (BLDO1)
/PMU.Vb2: C85.2, TP74.1, U18.14 (BLDO2)
/PMU.Vcpu: C86.2, TP82.1, U18.10 (CPULDOS)
/PMU.Vd1: C83.2, TP75.1, U18.20 (DLDO1/DC1SW)
/PMU.Vd2: C87.2, TP76.1, U18.11 (DLDO2/DC4SW)
/PMU.Vo1: C78.2, L8.1, R71.2, TP69.1, TST-R29.1, U18.22 (LX1)
/PMU.Vo1.Sense: R70.1, R71.1, TP19.1, U8.38 (GPIO33)
/PMU.Vo2: C77.2, L7.1, TP70.1, U18.26 (FB2)
/PMU.Vo3: C75.2, L5.1, TP71.1, U18.4 (FB3)
/PMU.Vo4: C76.2, L6.1, TP72.1, U18.8 (LX4)
/PMU.Vref: C73.2, TP16.1, TP83.1, U8.28 (SPICS1), U18.2 (VREF)
/PMU.Vsys: C88.2, C89.2, C91.2, C92.2, C93.2, C94.2, R66.2, R67.2, TP81.1, U18.6 (VIN3), U18.7 (VIN4), U18.13 (BLDOIN), U18.17 (ALDOIN), U18.23 (VIN1), U18.24 (VIN2), U18.34 (VSYS), U18.36 (VMID)
/POE_5V: C61.1, C64.1, D11.2, U14.1 (+VDC), U14.2 (+VDC)
/RC.OTHR: J8.1, U8.18 (GPIO13)
/RC.PAN: J5.1, U8.15 (GPIO10)
/RC.PWR: R47.2, U8.14 (GPIO9)
/RC.ROT: J7.1, U8.17 (GPIO12)
/RC.TILT: J6.1, U8.16 (GPIO11)
/RC.VDD: J5.2, J6.2, J7.2, J8.2, Q2.3 (D)
/RF1: C12.1, L3.1, U7.1 (LNA_IN)
/RF2: ANT1.1 (ANT), C15.1, L3.2, TP31.1, U8.1 (LNA_IN)
/SD.CLK: CARD1.5 (CLX), R31.2, U7.12 (GPIO7)
/SD.CS: CARD1.2 (CD/DAT3), R29.2, U7.9 (GPIO4)
/SD.MISO: CARD1.7 (DAT0), R32.2, U7.10 (GPIO5)
/SD.MOSI: CARD1.3 (CMD), R30.2, U7.11 (GPIO6)
/SPK.BCLK: U7.42 (GPIO37), U15.16 (BCLK)
/SPK.DIN: U7.41 (GPIO36), U15.1 (DIN)
/SPK.LRCLK: U7.27 (GPIO21), U15.14 (LRCLK)
/SPK.MIC: CN1.4, TP85.1
/SPK.MODE: R43.2, U15.4 (SD_MODE#)
/SPK.OutN: C66.2, CN1.1, J10.2, U15.10 (OUTN)
/SPK.OutP: C67.1, CN1.2, CN1.3, U15.9 (OUTP)
/SPK.OutPS: CN1.5, CN1.6, J10.1
/TEMP.DQ: U8.24 (GPIO18), U12.1 (DQ)
/U0RXD: J3.2, JP1.1 (A), U7.50 (U0RXD)
/U0TXD: J3.1, JP2.1 (A), U7.49 (U0TXD)
/USB_CC1: J1.A5 (CC1), R4.1
/USB_CC2: J1.B5 (CC2), R5.1
/USB_D+: R11.2, U3.3 (I/O2), U3.4 (I/O2), U7.26 (GPIO20/USB_D+)
/USB_D-: R10.2, U3.1 (I/O1), U3.6 (I/O1), U7.25 (GPIO19/USB_D-)
/USB_PRT_D+: J1.A6 (D+), J1.B6 (D+), R11.1
/USB_PRT_D-: J1.A7 (D-), J1.B7 (D-), R10.1
/VBus.Sense: R68.1, R69.1, TP9.1, U8.19 (GPIO14)
/VDCDC5: C95.2, C97.2, L9.1, TP84.1, U18.32 (GPIO1/FB5/RTC/LDO2)
/W_RD_N: J9.6, T1.9
/W_RD_OUT_N: C50.2, R48.1, U9.5 (RXN)
/W_RD_OUT_P: C51.2, R49.1, U9.6 (RXP)
/W_RD_P: J9.3, T1.11
/W_RXCM: D6.3, T1.10
/W_TD_N: J9.2, T1.14
/W_TD_OUT_N: R44.1, T1.3, U9.1 (TXN)
/W_TD_OUT_P: R46.1, T1.1, U9.2 (TXP)
/W_TD_P: J9.1, T1.16
/W_TXCM: D6.4, T1.15
/W_VN: D5.3, J9.7, J9.8, R59.2
/W_VP: D5.4, J9.4, J9.5, R60.2
Earth: BOOT1.3 (C), BOOT2.3 (C), BT1.1, C1.2, C2.2, C3.2, C4.2, C5.2, C6.2, C7.2, C8.2, C9.2, C10.2, C11.1, C12.2, C13.1, C14.2, C15.2, C16.2, C17.2, C18.2, C19.1, C20.1, C21.1, C22.1, C23.1, C24.2, C25.2, C26.1, C27.2, C28.2, C29.2, C30.2, C31.2, C32.2, C33.2, C34.1, C35.1, C36.1, C37.1, C38.1, C39.2, C40.2, C41.1, C42.2, C43.1, C44.2, C45.1, C46.1, C47.1, C48.2, C49.1, C52.2, C53.2, C54.2, C55.2, C56.1, C57.1, C58.1, C59.1, C60.2, C61.2, C62.1, C63.2, C64.2, C66.1, C67.2, C68.2, C69.1, C70.1, C71.1, C72.1, C73.1, C74.2, C75.1, C76.1, C77.1, C78.1, C79.1, C80.1, C81.1, C82.1, C83.1, C84.1, C85.1, C86.1, C87.1, C88.1, C89.1, C90.1, C91.1, C92.1, C93.1, C94.1, C95.1, C96.1, C97.1, CARD1.6 (VSS), CARD1.10, CARD1.11, CARD1.12, CARD1.13, D3.1, D4.1, D8.1, D9.3 (GND), D10.1, D12.1, D13.1 (C), D16.1 (C), D17.1 (C), D18.1 (C), FPC1.2 (2_GND), FPC1.15 (15_GND), J1.A12B1 (GND), J1.B12A1 (GND), J1.S1 (SHIELD)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
unnamed: C3.1, R1.1, Y1.1 (OSC)
unnamed: C4.1, R2.1, Y2.1 (OSC)
unnamed: C8.1, L1.2, R76.1, TST-R2.1
unnamed: C34.2, R20.2, R21.1, X1.3 (OSC)
unnamed: C35.2, L4.2, TST-R12.1
unnamed: C50.1, T1.8
unnamed: C51.1, T1.6
unnamed: C52.1, R45.1, T1.2
unnamed: C53.1, R48.2, R49.2, T1.7
unnamed: C54.1, C55.1, TST-R18.1, U15.7 (VDD), U15.8 (VDD)
unnamed: C65.2, R59.1, R60.1, R61.1, R62.1
unnamed: C68.1, R61.2, R62.2
unnamed: CARD1.8 (DAT1), TP45.1
unnamed: CARD1.1 (DAT2), TP44.1
unnamed: CARD1.CD, TP46.1
unnamed: C38.2, CARD1.4 (VDD), R29.1, R30.1, R31.1, R32.1, TST-R13.1
unnamed: D1.2, J1.A9B4 (VBUS), J1.B9A4 (VBUS)
unnamed: D2.2, J2.A9B4 (VBUS), J2.B9A4 (VBUS)
unnamed: D3.2, R34.2
unnamed: D4.2, R35.2
unnamed: D5.1 (+), D6.1 (+), D7.1, U14.5 (VIN+), U14.6 (VIN+)
unnamed: D5.2 (-), D6.2 (-), D7.2, U14.7 (VIN-), U14.8 (VIN-)
unnamed: D8.2, R50.1
unnamed: C58.2, D9.2 (VDD), TST-R19.1
unnamed: D10.2, R53.1
unnamed: D11.1, TST-R25.1
unnamed: D12.2, R65.2
unnamed: D13.2 (A), R64.2
unnamed: D14.2, R66.1
unnamed: D15.2, R67.1
unnamed: D16.2 (A), R78.2
unnamed: D17.2 (A), R81.2
unnamed: D18.2 (A), R84.2
unnamed: DISP1.11 (NC), TP49.1
unnamed: FPC1.1 (1_NC), TP10.1
unnamed: FPC1.23 (23_Y1-NC), TP11.1, TP128.1, TP129.1
unnamed: FPC1.24 (24_Y0-NC), TP12.1
unnamed: FPC1.25, TP14.1
unnamed: FPC1.26, TP13.1
unnamed: J11.1, Q5.3 (D)
unnamed: J12.1, Q4.3 (D), R64.1
unnamed: J13.1, Q3.3 (D), R65.1
unnamed: BT1.2, C96.2, J14.1, U18.33 (BAT)
unnamed: J15.1, U18.27 (VBACKUP)
unnamed: J16.1, NTC1.2, U18.31 (TS)
unnamed: J17.1, Q6.3 (D), R78.1
unnamed: J18.1, Q7.3 (D), R81.1
unnamed: J19.1, Q8.3 (D), R84.1
unnamed: JP3.2 (B), JP4.2 (B), JP5.2 (B), JP6.2 (B), U15.2 (GAIN_SLOT)
unnamed: JP4.1 (A), R40.2
unnamed: JP6.1 (A), R41.2
unnamed: JP7.1 (A), TST-R20.1
unnamed: JP8.3 (B), TST-R21.1
unnamed: L2.1, TP3.1, TST-R5.2
unnamed: PB3.1 (A), U18.30 (PWRON)
unnamed: C16.1, Q1.3 (D), U5.3 (VI), U6.3 (VI)
unnamed: Q1.1 (G), R14.2, R15.1
unnamed: Q1.2 (S), R14.1, TST-R6.1
unnamed: Q2.1 (G), R42.2, R47.1
unnamed: Q2.2 (S), R42.1, TST-R17.1
unnamed: Q3.1 (G), R54.2, R57.1
unnamed: Q3.2 (S), R54.1, TST-R22.1
unnamed: Q4.1 (G), R55.2, R58.1
unnamed: Q4.2 (S), R55.1, TST-R23.1
unnamed: Q5.1 (G), R56.2, R63.1
unnamed: Q5.2 (S), R56.1, TST-R24.2
unnamed: Q6.1 (G), R8.2, R77.1
unnamed: Q6.2 (S), R8.1, TST-R30.1
unnamed: Q7.1 (G), R79.2, R80.1
unnamed: Q7.2 (S), R79.1, TST-R31.1
unnamed: Q8.1 (G), R82.2, R83.1
unnamed: Q8.2 (S), R82.1, TST-R32.1
unnamed: R16.1, R17.1, R18.1, TST-R7.2
unnamed: R28.1, U9.23 (RSVD)
unnamed: R43.1, TST-R16.2
unnamed: R74.1, R75.1
unnamed: R74.2, R76.2
unnamed: T1.4, TP61.1
unnamed: T1.5, TP60.1
unnamed: T1.12, TP54.1
unnamed: T1.13, TP55.1
unnamed: TP35.1, U9.38 (RSVD)
unnamed: TP36.1, U9.39 (RSVD)
unnamed: TP37.1, U9.40 (RSVD)
unnamed: TP38.1, U9.41 (RSVD)
unnamed: TP39.1, U9.42 (RSVD)
unnamed: TP63.1, U15.5 (N.C.)
unnamed: TP64.1, U15.6 (N.C.)
unnamed: TP66.1, U15.13 (N.C.)
unnamed: TP67.1, U15.12 (N.C.)
unnamed: R3.2, U1.1 (EN)
unnamed: R9.1, R75.2, U1.5 (FB)
unnamed: L1.1, U1.3 (SW)
unnamed: C1.1, R3.1, TP1.1, TST-R1.2, U1.4 (VIN)
unnamed: TST-R3.2, U3.5 (VBUS)
unnamed: TST-R4.2, U4.5 (VBUS)
unnamed: C17.1, C19.2, TST-R8.1, U5.2 (VO)
unnamed: C18.1, C20.2, TST-R9.1, U6.2 (VO)
unnamed: C23.2, C24.1, C25.1, C27.1, C30.1, TST-R10.1, U7.2 (VDD3P3), U7.3 (VDD3P3), U7.20 (VDD3P3_RTC), U7.55 (VDDA), U7.56 (VDDA)
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

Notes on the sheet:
MISC OUTPUTS
BATTERY PMU / GUAGE
GPIO15
2GPIO10
RGB Status LED
GPIO10
GPIO37
2GPIO21
GPIO28
RST Button
expected risky area -- camera connector pinout, is pin1 really pin 1 not 24? -- I2S microphones and amplifier, should they be the same lines like code suggests -- I2C, does this need pull up, or can internal pullup suffice? -- POE ethernet, complete unknown. Fingers crossed. TODO -- make office con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
GPIO31
2GPIO13
FB is 0.6V, with R9 at 100k, high side wants 450k for 3.3V out.
GPIO4
OTHER
VBUS + 3V3
GPIO21
GPIO12
NOR FLASH
(CL(Load) - Cs(Stray)) * 2 = Capacitance (10p - +/-4p) * 2 = 10p
MICROPHONES
GPIO46
2GPIO2
GPIO6
TILT
2GPIO18
2GPIO31
GPIO13
GPIO14
Boot Button
2GPIO20
2GPIO36
Current Sense
Crystals
GPIO36
GPIO34
NP = Normal P = Directly in Flash
HSE / LSE
GPIO30

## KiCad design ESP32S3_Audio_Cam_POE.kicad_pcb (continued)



Board: 4 copper layers, 109.3 x 129.7 mm, 443 parts (89 on the bottom side), 306 nets.

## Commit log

2025-05-09 Initial draft commit. Non Functional.
    [ESP32S3_Audio_Cam_POE.kicad_pcb, ESP32S3_Audio_Cam_POE.kicad_sch]
2025-05-09 draft commit
    [ESP32S3_Audio_Cam_POE.kicad_sch]
2025-05-09 draft check in
    [ESP32S3_Audio_Cam_POE.kicad_sch]
2025-05-10 Draft commit, needs routing, schematic is probably mostly OK. Footprints are roughly located.
    [ESP32S3_Audio_Cam_POE.kicad_pcb, ESP32S3_Audio_Cam_POE.kicad_sch]
2025-05-22 draft commit, mostly added notes
    [ESP32S3_Audio_Cam_POE.kicad_sch]
2025-05-27 DRAFT added AXP2101 battery circuit
    [ESP32S3_Audio_Cam_POE.kicad_sch]
2025-05-28 DRAFT added misc outputs, PMU and resolved some TODO notes.
    [ESP32S3_Audio_Cam_POE.kicad_pcb, ESP32S3_Audio_Cam_POE.kicad_sch]
2025-05-30 DRAFT added mic jack.
    [ESP32S3_Audio_Cam_POE.kicad_pcb, ESP32S3_Audio_Cam_POE.kicad_sch]
2025-08-12 Draft Updated ESP32-S3 now includes 8MB internal PSRAM
    [ESP32S3_Audio_Cam_POE.kicad_sch]
2025-08-14 Draft Misc changes, layout still needs a lot of work.
    [ESP32S3_Audio_Cam_POE.kicad_pcb, ESP32S3_Audio_Cam_POE.kicad_sch]
2025-08-15 Draft misc layout, layout still needs a lot of work
    [ESP32S3_Audio_Cam_POE.kicad_pcb, ESP32S3_Audio_Cam_POE.kicad_sch]
2025-08-16 DRAFT commit, still needs lots of layout work.
    [ESP32S3_Audio_Cam_POE.kicad_sch]
2025-08-18 Draft Commit, probably OK-ish. Lots of errors and warnings, but probably not important.
    [ESP32S3_Audio_Cam_POE.kicad_sch]
2025-08-24 DRAFT fixed many things with ANT1, added ANT2, moved MicJack to edge of PCB
    [ESP32S3_Audio_Cam_POE.kicad_sch]
2025-08-25 Added 1st spin files
    [bom.csv, designators.csv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]
2025-08-26 DRAFT added smaller PCB design
    [ESP32S3_Audio_Cam_POE_Smaller.kicad_pcb, ESP32S3_Audio_Cam_POE_Smaller.kicad_sch]
2025-08-26 Draft smaller board.
    [ESP32S3_Audio_Cam_POE_Smaller.kicad_pcb, ESP32S3_Audio_Cam_POE_Smaller.kicad_sch]
2025-08-27 Reverted Smaller
    [ESP32S3_Audio_Cam_POE_Smaller.kicad_pcb, ESP32S3_Audio_Cam_POE_Smaller.kicad_sch]
2025-08-27 Draft Medium
    [ESP32S3_Audio_Cam_POE_Medium.kicad_pcb, ESP32S3_Audio_Cam_POE_Medium.kicad_sch]
2025-08-28 Draft Medium re-annotated.
    [ESP32S3_Audio_Cam_POE_Medium.kicad_pcb, ESP32S3_Audio_Cam_POE_Medium.kicad_sch]
2025-08-29 Medium R0.1 production files created
    [bom.csv, designators.csv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]
2025-08-29 Updated name
    [bom.csv, designators.csv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]
2025-08-29 Added smaller production files.
    [ESP32S3_Audio_Cam_POE_Smaller.kicad_pcb, bom.csv, designators.csv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]
2025-08-29 Changed Vdrive2 net from PMU.Vo1 to VDCDC5
    [ESP32S3_Audio_Cam_POE_Medium.kicad_pcb, ESP32S3_Audio_Cam_POE_Medium.kicad_sch]
2025-08-29 Changed input power from 3.3V to 5V.
    [ESP32S3_Audio_Cam_POE_Medium.kicad_pcb, ESP32S3_Audio_Cam_POE_Medium.kicad_sch]
2025-08-29 flipped RC servo headers to back side.
    [ESP32S3_Audio_Cam_POE_Medium.kicad_pcb]
2025-09-02 Moved PCB edge to make easier to get SD card out.
    [ESP32S3_Audio_Cam_POE_Medium.kicad_pcb]
2025-09-04 V0.1 updates added pictures and exported 3D file
    [ESP32S3_Audio_Cam_POE_Medium.kicad_pcb]
2025-09-04 Updated PCB edge to allow easier access to SD card.
2025-09-04 updated smaller board layout
    [ESP32S3_Audio_Cam_POE_Smaller.kicad_pcb]
2025-12-23 Added LORA module rough draft
    [ESP32S3_Audio_Cam_POE.kicad_sch]
2025-12-27 Draft commit added LORA
    [ESP32S3_Audio_Cam_POE.kicad_sch]
2026-01-19 Minor updates, looks like it's ready for 1st spin.
    [ESP32S3_Audio_Cam_POE.kicad_sch, bom.csv, designators.csv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]
2026-01-19 added C107 to help with surge suppression
    [ESP32S3_Audio_Cam_POE.kicad_sch]
2026-01-20 Draft commit, added 33 ohms to camera lines to prevent cross talk
    [ESP32S3_Audio_Cam_POE.kicad_sch]
2026-06-14 updated to lower cost mic
    [ESP32S3_Audio_Cam_POE.kicad_sch]
2026-06-14 added mic.sck, mic.sd, and mic.ws term resistors
    [ESP32S3_Audio_Cam_POE.kicad_sch]
2026-06-14 moved nets off of conflicting psram IO.
    [ESP32S3_Audio_Cam_POE.kicad_sch]
2026-06-14 combined speaker and mic I2S signals making progress on IO count.
    [ESP32S3_Audio_Cam_POE.kicad_sch]
2026-06-14 re-connected digital signals now without conflict on PSRAM IO. Layout needs updating.
    [ESP32S3_Audio_Cam_POE.kicad_sch]
2026-06-14 updated pin out layout is now off of PSRAM IO.
    [ESP32S3_Audio_Cam_POE.kicad_sch]
2026-06-14 flipped D6 and D7 back to original pins, needed for internal connects.
    [ESP32S3_Audio_Cam_POE.kicad_sch]
